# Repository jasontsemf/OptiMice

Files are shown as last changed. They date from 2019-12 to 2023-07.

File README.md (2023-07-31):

# OptiMice

OptiMice

## Intro

> "Bespoke computer mice powered by AI and 3D printing"

[Learn more about the project](https://jasontsemf.github.io/optimice.html) on Jason's portfolio site

## Complementary Web Platform

[Live on Back4App](https://optimice-jasontsemf.b4a.run).

[GitHub Repo](https://github.com/jasontsemf/OptimiceDashboard) of the web platform

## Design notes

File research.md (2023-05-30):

# Links
[PixArt Imaging Inc. - PRODUCTS - PAW3519DL-TKST ](https://www.pixart.com/products-detail/22/PAW3519DL-TKST)

[PixArt Imaging Inc. - PRODUCTS - PAW3212DB-TJDT ](https://www.pixart.com/products-detail/20/PAW3212DB-TJDT)

[PAW3519DL Datasheet, PDF - Alldatasheet](https://www.alldatasheet.com/view.jsp?Searchword=PAW3519DL)

[PAW3205DB-TJ3T Datasheet PDF - Pixart Imaging Inc.](https://pdf1.alldatasheet.com/datasheet-pdf/view/558655/PIXART/PAW3205DB-TJ3T.html)

[PAW3515DB Datasheet (PDF) - Pixart Imaging Inc.](https://pdf1.alldatasheet.com/datasheet-pdf/view/558660/PIXART/PAW3515DB.html)

[Arduino HID Project 2.6.1](https://github.com/NicoHood/HID/blob/master/Readme.md)

[Computer mouse](https://homofaciens.de/technics-base-circuits-computer-mouse_en.htm)

[Optical mouse hacking, part 1](https://conorpeterson.wordpress.com/2010/06/04/optical-mouse-hacking-part-1/)

[Hacked Optical Mouse](https://hackteria.org/wiki/Hacked_Optical_Mouse)

[brush_mouse.ino inoセンサなしで動くよう微調整とUIブラッシュアップ](https://github.com/moritanian/BrushMouse/blob/master/brush_mouse/brush_mouse.ino)

[DeqingSun/UX-Week-2018-Workshop](https://github.com/DeqingSun/UX-Week-2018-Workshop/tree/developPackage)

[sandeepmistry/arduino-BLEPeripheral: An Arduino library for creating custom BLE peripherals with Nordic Semiconductor's nRF8001 or nR51822](https://github.com/sandeepmistry/arduino-BLEPeripheral)

[sandeepmistry/arduino-nRF5: Arduino Core for Nordic Semiconductor nRF5 based boards](https://github.com/sandeepmistry/arduino-nRF5#flashing-a-softdevice)

[arduino-BLEPeripheral/examples at master · sandeepmistry/arduino-BLEPeripheral](https://github.com/sandeepmistry/arduino-BLEPeripheral/tree/master/examples)

[sandeepmistry/arduino-nRF5](https://github.com/sandeepmistry/arduino-nRF5#flashing-a-softdevice)

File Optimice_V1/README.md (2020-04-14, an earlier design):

# OptiMice

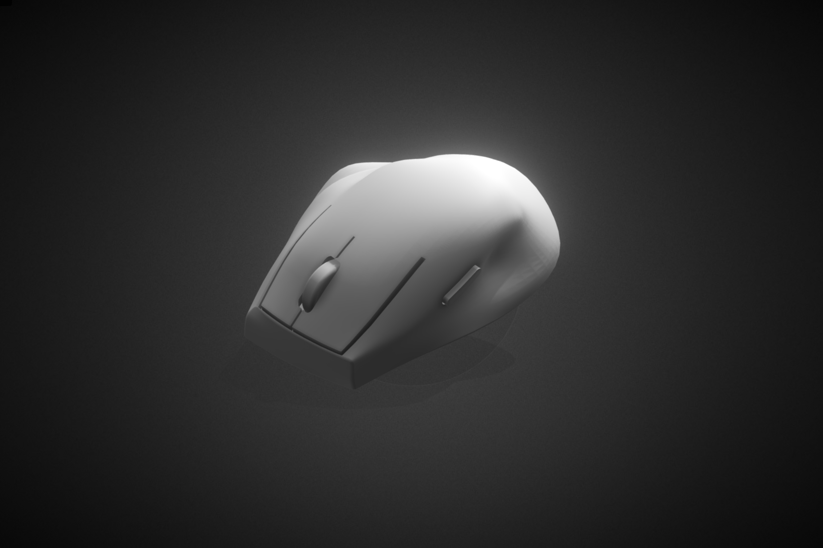
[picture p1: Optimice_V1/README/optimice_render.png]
OptiMice


## Intro

> "OptiMice is a novel, online customer experience which offers tailor-made computer mice to professional computer users who value ergonomics, productivity and customization by harnessing 3D printing and photogrammetry technology."

[Learn more about the project](https://jasontsemf.github.io/optimice.html) on Jason's portfolio site

## Complementary Web Platform

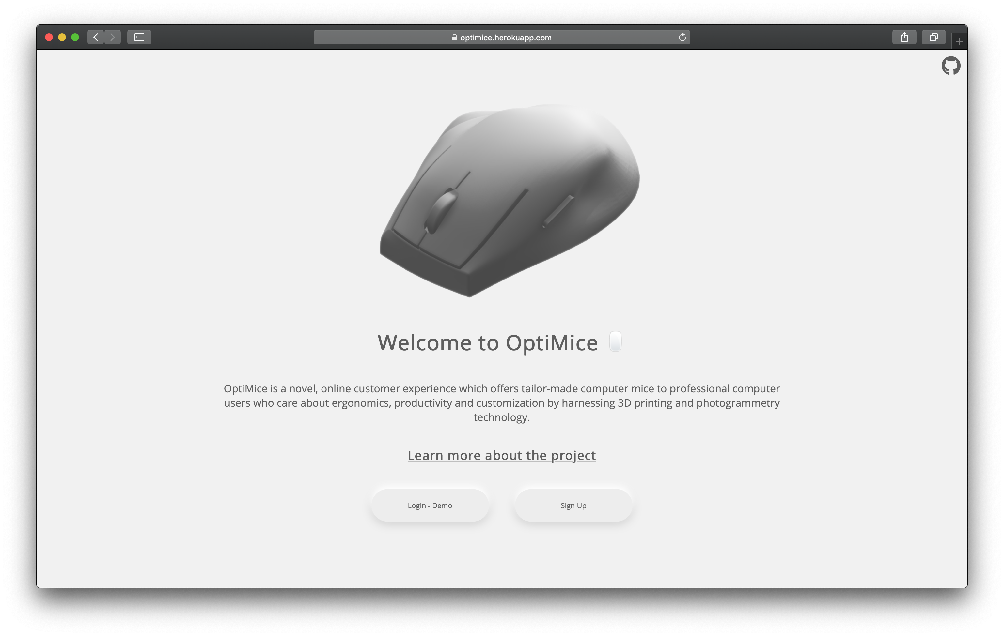
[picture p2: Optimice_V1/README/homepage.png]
Web Platform


[Live on Heroku](https://optimice.herokuapp.com/) working in progress.

[GitHub Repo](https://github.com/jasontsemf/OptimiceDashboard) of the web platform

## Video Demos

OptiMice in 30sec (http://www.youtube.com/watch?v=HUqzL-0pyRI "OptiMice in 30sec")

OptiMice Optical sensor over Bluetooth (http://www.youtube.com/watch?v=QQ9oYC2MPyM "OptiMice Optical sensor over Bluetooth")

## Presentation

[Link to Google Slide](https://docs.google.com/presentation/d/1tQIoXVUgUf5d4TsgJXfUaHyZ3wD5bcfRX4gObf0h1YQ/edit?usp=sharing "OptiMice - Prototyping Electronics Devices Final Present")

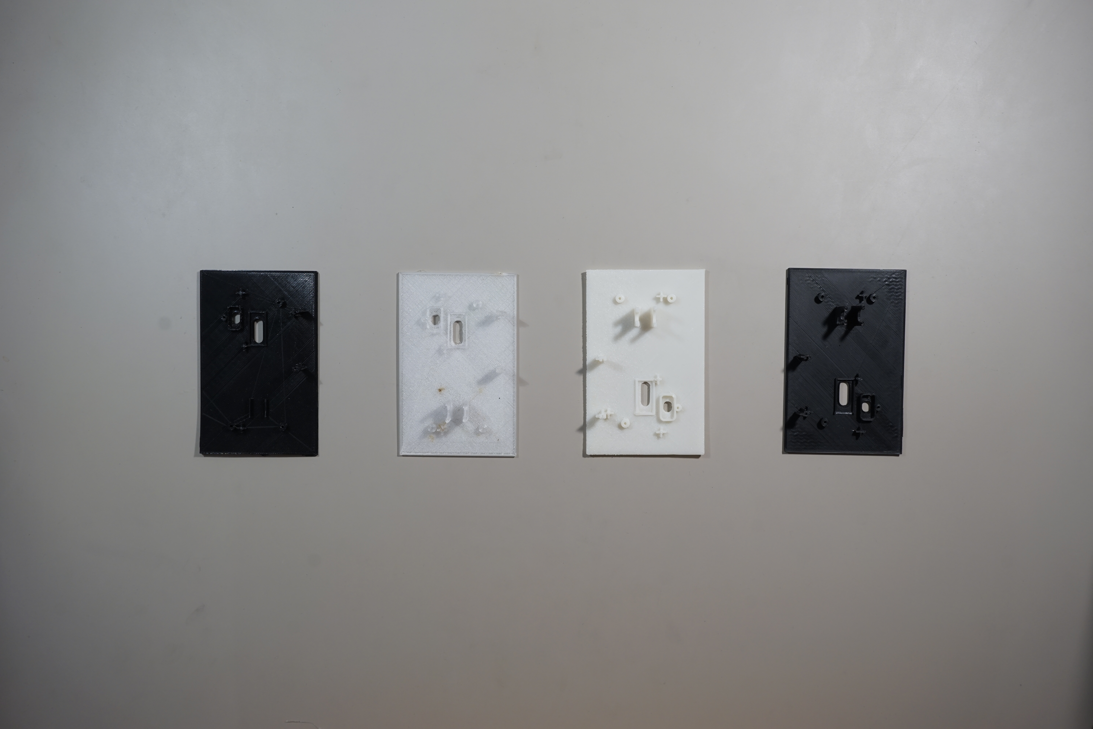
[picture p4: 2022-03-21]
Optimice_V2/img/_DSC0002.JPG

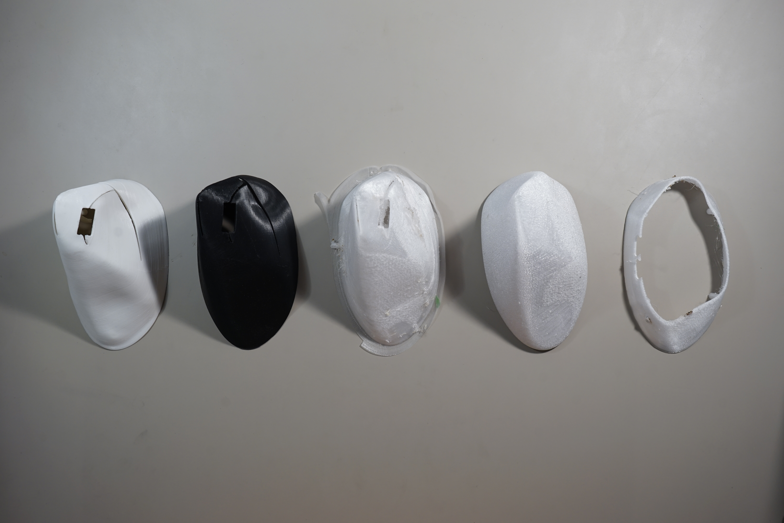
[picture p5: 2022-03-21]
Optimice_V2/img/_DSC0004.JPG

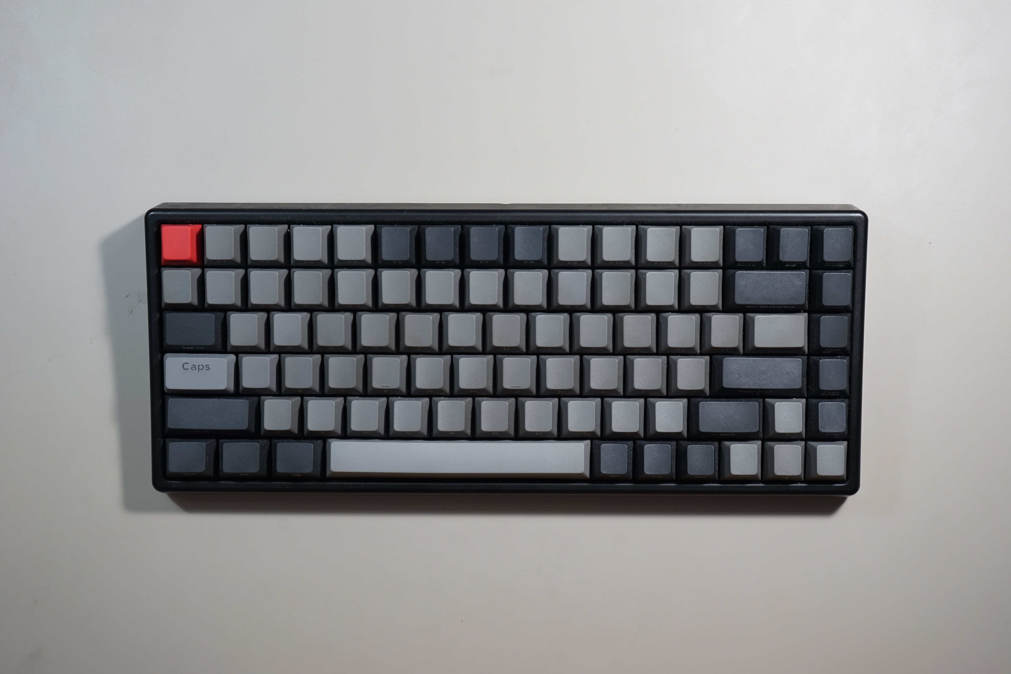
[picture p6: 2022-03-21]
Optimice_V2/img/_DSC0005.JPG

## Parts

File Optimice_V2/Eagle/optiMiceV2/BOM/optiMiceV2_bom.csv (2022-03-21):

Part | Value | Device | Package | Description | AVAILABILITY | BOM | CATEGORY | COMMENT | CURRENT_RATING | DESCRIPTION | MANUFACTURER | MF | MP | MPN | OPERATING_TEMP | PACKAGE | PART_STATUS | POPULARITY | PRICE | PROD_ID | PURCHASE-URL | ROHS_COMPLIANT | SERIES | SPICEPREFIX | SUB-CATEGORY | THERMALLOSS | TYPE | VALUE
BAT | B2B-PH-K-S(LF)(SN) | B2B-PH-K-S(LF)(SN) | JST_B2B-PH-K-S(LF)(SN) | PH Series 2 Position 2 mm Pitch Through Hole Top Entry Shrouded Header Check prices | Good |  |  |  |  | Connector Header Through Hole 2 position 0.079 (2.00mm) |  | JST Sales | B2B-PH-K-S(LF)(SN) |  |  | None |  |  | None |  | https://pricing.snapeda.com/search/part/B2B-PH-K-S(LF)(SN)/?ref=eda
C1 | 1uF | C-USC0805K | C0805K | CAPACITOR, American symbol |  |  |  |  |  |  |  |  |  |  |  |  |  | 19 |  |  |  |  |  | C
C2 | 10uF | C-USC0805K | C0805K | CAPACITOR, American symbol |  |  |  |  |  |  |  |  |  |  |  |  |  | 19 |  |  |  |  |  | C
C3 | 0.1uF | C-EUC0805K | C0805K | CAPACITOR, European symbol |  |  |  |  |  |  |  |  |  |  |  |  |  | 52 |  |  |  |  |  | C
C4 | 100nF | C-EUC0805 | C0805 | CAPACITOR, European symbol |  |  |  |  |  |  |  |  |  |  |  |  |  | 88 |  |  |  |  |  | C
C5 | 100nF | C-EUC0805 | C0805 | CAPACITOR, European symbol |  |  |  |  |  |  |  |  |  |  |  |  |  | 88 |  |  |  |  |  | C
C6 | 10uF | C-EUC0805 | C0805 | CAPACITOR, European symbol |  |  |  |  |  |  |  |  |  |  |  |  |  | 88 |  |  |  |  |  | C
C7 | 4.7uF | C-EUC0805 | C0805 | CAPACITOR, European symbol |  |  |  |  |  |  |  |  |  |  |  |  |  | 88 |  |  |  |  |  | C
C8 | 22uF | C-EUC0805 | C0805 | CAPACITOR, European symbol |  |  |  |  |  |  |  |  |  |  |  |  |  | 88 |  |  |  |  |  | C
HOLE1 | HOLES_MOUNT-PAD-ROUND-0.096-NS | HOLES_MOUNT-PAD-ROUND-0.096-NS | HOLES_096-PAD-NS | MOUNTING PAD, round |  | EXCLUDE
HOLE2 | HOLES_MOUNT-PAD-ROUND-0.096-NS | HOLES_MOUNT-PAD-ROUND-0.096-NS | HOLES_096-PAD-NS | MOUNTING PAD, round |  | EXCLUDE
HOLE3 | HOLES_MOUNT-PAD-ROUND-0.096-NS | HOLES_MOUNT-PAD-ROUND-0.096-NS | HOLES_096-PAD-NS | MOUNTING PAD, round |  | EXCLUDE
HOLE4 | HOLES_MOUNT-PAD-ROUND-0.096-NS | HOLES_MOUNT-PAD-ROUND-0.096-NS | HOLES_096-PAD-NS | MOUNTING PAD, round |  | EXCLUDE
IC1 | TP4056 | TP4056 | SOP-8 |  | Unavailable |  |  |  |  | Complete single cell Li-Ion battery with a constant current / constant voltage linear charger |  | NanJing Top Power ASIC Corp. | TP4056 |  |  | Package |  |  | None
IC2 | DW01A | DW01A | SOT23-6 |  | Unavailable |  |  |  |  | One Cell Lithium-ion/Polymer Battery Protection IC |  | Fortune Semiconductor | DW01A |  |  | SOT-23-6 Fortune Semiconductor |  |  | None
J1 | 10103592-0001LF | 10103592-0001LF | AMPHENOL_10103592-0001LF | Conn Micro USB Type B RCP 5 POS 0.65mm Solder RA SMD 5 Terminal 1 Port T/R Check prices | Good |  |  |  |  | USB - micro B USB 2.0 Receptacle Connector 5 Position Surface Mount, Right Angle | Through Hole |  | Amphenol ICC (FCI) | 10103592-0001LF |  |  | None |  |  | None |  | https://pricing.snapeda.com/search/part/10103592-0001LF/?ref=eda
J3 | 5V | CONN_02 | 1X02 | Multi connection point. Often used as Generic Header-pin footprint for 0.1 inch spaced/style header connections
J4 | PROG | CONN_04 | 1X04 | Multi connection point. Often used as Generic Header-pin footprint for 0.1 inch spaced/style header connections |  |  |  |  |  |  |  |  |  |  |  |  |  |  |  | CONN-09696
J7 | B2B-PH-K-S(LF)(SN) | B2B-PH-K-S(LF)(SN) | JST_B2B-PH-K-S(LF)(SN) | PH Series 2 Position 2 mm Pitch Through Hole Top Entry Shrouded Header Check prices | Good |  |  |  |  | Connector Header Through Hole 2 position 0.079 (2.00mm) |  | JST Sales | B2B-PH-K-S(LF)(SN) |  |  | None |  |  | None |  | https://pricing.snapeda.com/search/part/B2B-PH-K-S(LF)(SN)/?ref=eda
J8 | B2B-PH-K-S(LF)(SN) | B2B-PH-K-S(LF)(SN) | JST_B2B-PH-K-S(LF)(SN) | PH Series 2 Position 2 mm Pitch Through Hole Top Entry Shrouded Header Check prices | Good |  |  |  |  | Connector Header Through Hole 2 position 0.079 (2.00mm) |  | JST Sales | B2B-PH-K-S(LF)(SN) |  |  | None |  |  | None |  | https://pricing.snapeda.com/search/part/B2B-PH-K-S(LF)(SN)/?ref=eda
L1 | 4.7uH | L_CHIP-0805(2012-METRIC) | INDC2009X120 | Inductor Fixed - Generic |  |  | Inductor |  |  |  |  |  |  |  |  |  |  |  |  |  |  |  |  |  | Fixed
LED1 | RED | LED5MM | LED5MM | LED |  |  |  |  |  |  |  |  |  |  |  |  |  | 93
LED_G | GREEN | LEDCHIP-LED0805 | CHIP-LED0805 | LED |  |  |  |  |  |  |  |  |  |  |  |  |  | 68
LED_R | RED | LEDCHIP-LED0805 | CHIP-LED0805 | LED |  |  |  |  |  |  |  |  |  |  |  |  |  | 68
Q1 | FS8205A | FS8205A | SOP65P640X120-8N | N/A | Unavailable |  |  |  |  |  |  | Fortune Semiconductor | FS8205A |  |  | Package |  |  | None
R1 | 10K | R-US_R0805 | R0805 | RESISTOR, American symbol |  |  |  |  |  |  |  |  |  |  |  |  |  | 85 |  |  |  |  |  | R
R2 | 10K | R-US_R0805 | R0805 | RESISTOR, American symbol |  |  |  |  |  |  |  |  |  |  |  |  |  | 85 |  |  |  |  |  | R
R3 | 10K | R-US_R0805 | R0805 | RESISTOR, American symbol |  |  |  |  |  |  |  |  |  |  |  |  |  | 85 |  |  |  |  |  | R
R4 | 10K | R-US_R0805 | R0805 | RESISTOR, American symbol |  |  |  |  |  |  |  |  |  |  |  |  |  | 85 |  |  |  |  |  | R
R5 | 10K | R-US_R0805 | R0805 | RESISTOR, American symbol |  |  |  |  |  |  |  |  |  |  |  |  |  | 85 |  |  |  |  |  | R
R6 | 22 | R-US_R0805 | R0805 | RESISTOR, American symbol |  |  |  |  |  |  |  |  |  |  |  |  |  | 85 |  |  |  |  |  | R
R7 | 1K | R-US_R0805 | R0805 | RESISTOR, American symbol |  |  |  |  |  |  |  |  |  |  |  |  |  | 85 |  |  |  |  |  | R
R8 | 1K | R-US_R0805 | R0805 | RESISTOR, American symbol |  |  |  |  |  |  |  |  |  |  |  |  |  | 85 |  |  |  |  |  | R
R9 | 1.2K | R-US_R0805 | R0805 | RESISTOR, American symbol |  |  |  |  |  |  |  |  |  |  |  |  |  | 85 |  |  |  |  |  | R
R10 | 1K | R-US_R0805 | R0805 | RESISTOR, American symbol |  |  |  |  |  |  |  |  |  |  |  |  |  | 85 |  |  |  |  |  | R
R11 | 100 | R-US_R0805 | R0805 | RESISTOR, American symbol |  |  |  |  |  |  |  |  |  |  |  |  |  | 85 |  |  |  |  |  | R
R12 | 10K | R-US_R0805 | R0805 | RESISTOR, American symbol |  |  |  |  |  |  |  |  |  |  |  |  |  | 85 |  |  |  |  |  | R
R13 | 10K | R-US_R0805 | R0805 | RESISTOR, American symbol |  |  |  |  |  |  |  |  |  |  |  |  |  | 85 |  |  |  |  |  | R
S1 | D2F-FL | D2F-FL | SW_D2F-FL | SWITCH SNAP ACTION SPDT 1A 125V Check prices | Good |  |  |  |  | SWITCH SNAP ACTION SPDT 1A 125V |  | Omron Electronics | D2F-FL |  |  | MQFP-44 Omron |  |  | None |  | https://pricing.snapeda.com/search/part/D2F-FL/?ref=eda
S2 | D2F-FL | D2F-FL | SW_D2F-FL | SWITCH SNAP ACTION SPDT 1A 125V Check prices | Good |  |  |  |  | SWITCH SNAP ACTION SPDT 1A 125V |  | Omron Electronics | D2F-FL |  |  | MQFP-44 Omron |  |  | None |  | https://pricing.snapeda.com/search/part/D2F-FL/?ref=eda
S3 | D2F-FL | D2F-FL | SW_D2F-FL | SWITCH SNAP ACTION SPDT 1A 125V Check prices | Good |  |  |  |  | SWITCH SNAP ACTION SPDT 1A 125V |  | Omron Electronics | D2F-FL |  |  | MQFP-44 Omron |  |  | None |  | https://pricing.snapeda.com/search/part/D2F-FL/?ref=eda
SW1 | MLL1200S | MLL1200S | SW_MLL1200S | Switch Slide SPDT Side Slide 0.3A 4VDC Gull Wing SMD Box Check prices | Good |  |  | 1437575-1 |  | Slide Switch SPDT Surface Mount, Right Angle |  | TE Connectivity | MLL1200S |  |  | None |  |  | None |  | https://pricing.snapeda.com/search/part/MLL1200S/?ref=eda
U$1 | NRF51822-02 | NRF51822-02 | WT51822-S2
U$2 | PAW3205TJ3T | PAW3205TJ3T | PAW3205 | Check prices | Bad |  |  |  |  | Optical Sensor 8-DIP Module |  | Broadcom Limited | ADNS-2080 |  |  | DIP-8 Broadcom Limited |  |  | None
U1 | TPS62203DBVR | TPS62203DBVR | SOT95P280X145-5N | Check prices | Good |  |  |  |  | 3.3-V Output, 300-mA, 95% Efficient Step-Down Converter in SOT-23 5-SOT-23 -40 to 85 |  | Texas Instruments | TPS62203DBVR |  |  | SOT-23-5 Texas Instruments |  |  | None |  | https://pricing.snapeda.com/search/part/TPS62203DBVR/?ref=eda
VR1 | EC10E1220501 | EC10E1220501 | TRIM_EC10E1220501 | Encoders 10mm 12 Res 24 Dtent 9mm mount height Check prices | Good |  |  |  |  | Encoders 10mm 12 Res 24 Dtent 9mm mount height |  | ALPS | EC10E1220501 |  |  | None |  |  | None |  | https://pricing.snapeda.com/search/part/EC10E1220501/?ref=eda

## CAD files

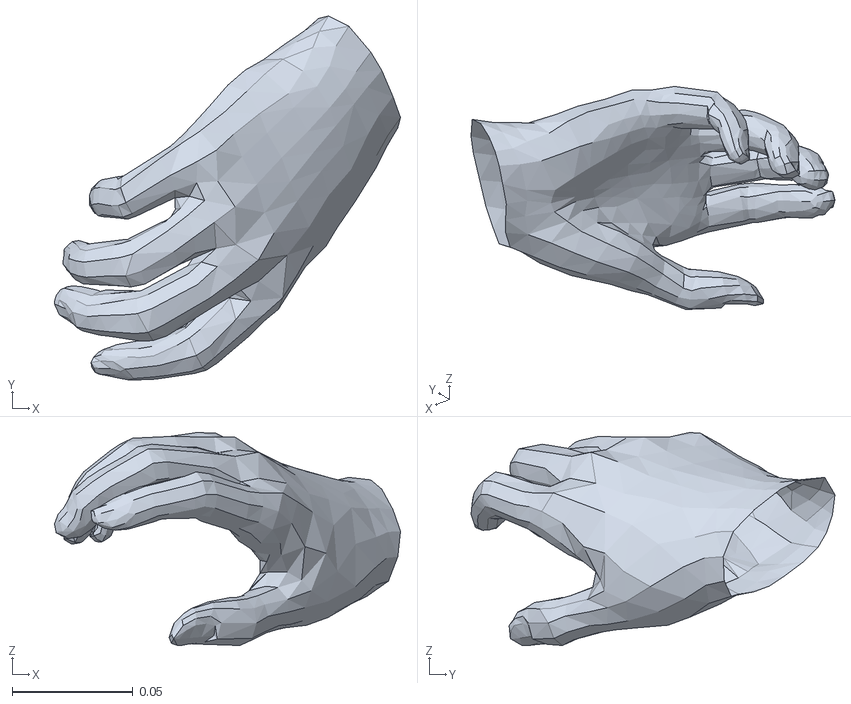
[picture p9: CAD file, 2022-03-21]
Optimice_V2/software/I2L-MeshNet_RELEASE/demo/close_to_perfect/output_mesh_lixel.obj
0.143 x 0.151 x 0.0882

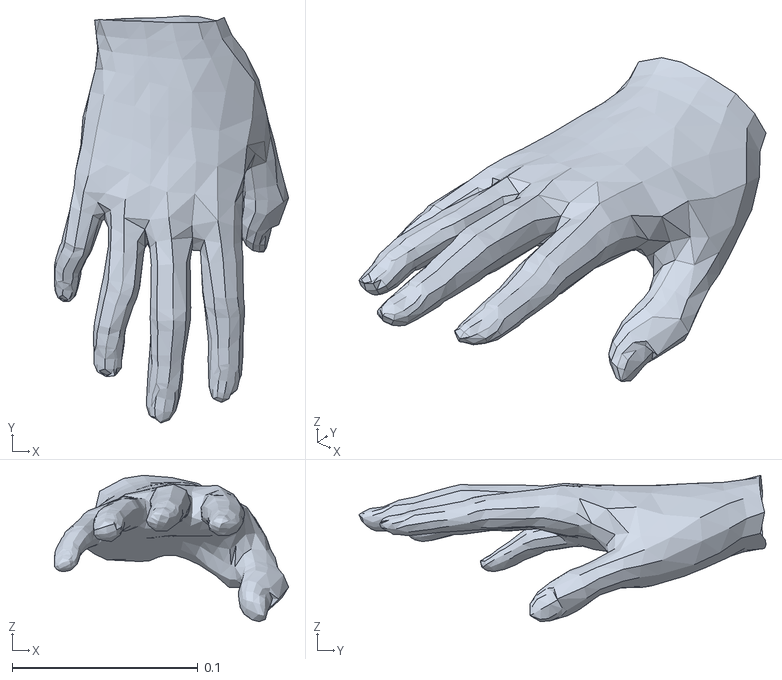
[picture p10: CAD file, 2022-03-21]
Optimice_V2/software/I2L-MeshNet_RELEASE/demo/flat/output_mesh_lixel.obj
0.126 x 0.219 x 0.0788

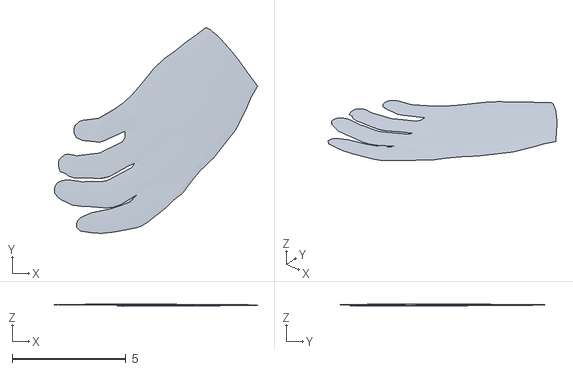
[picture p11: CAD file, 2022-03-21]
Optimice_V2/software/I2L-MeshNet_RELEASE/demo/output_mesh_lixel.obj
8.93 x 9.05 x 0.0882

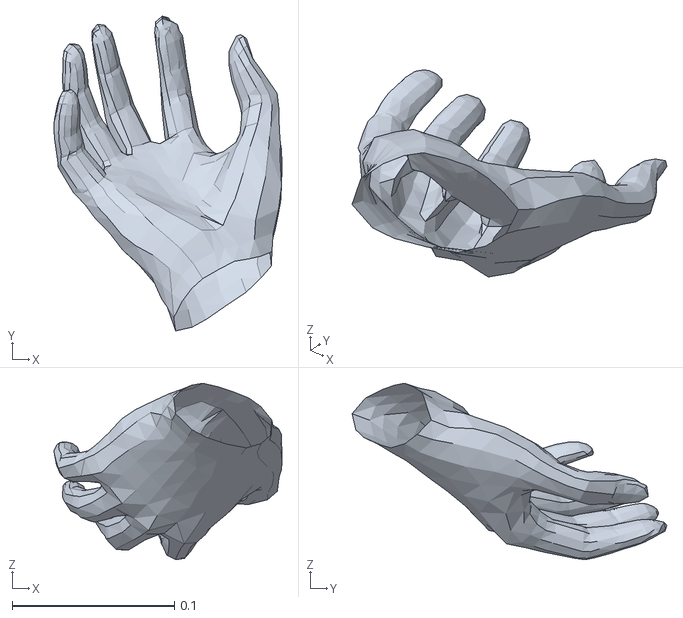
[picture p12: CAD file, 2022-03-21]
Optimice_V2/software/I2L-MeshNet_RELEASE/demo/quite_good/output_mesh_lixel.obj
0.141 x 0.194 x 0.109

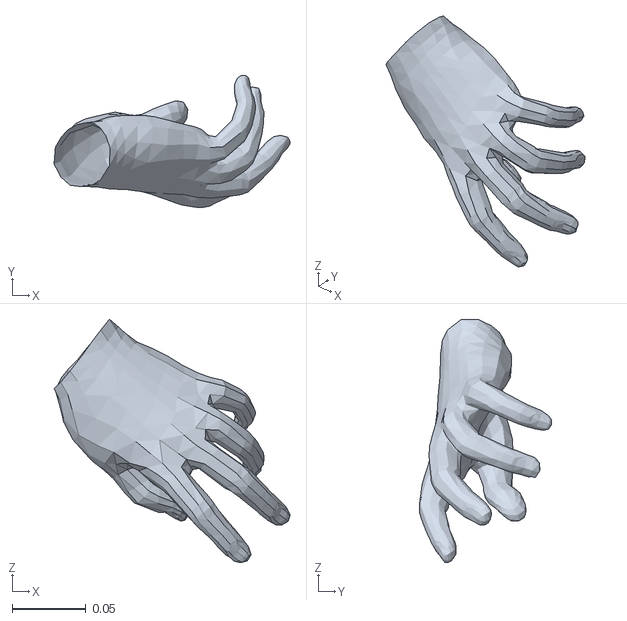
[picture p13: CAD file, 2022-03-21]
Optimice_V2/software/minimal-hand/capture/output_mesh_lixelMar112021181230.obj
0.16 x 0.09 x 0.165

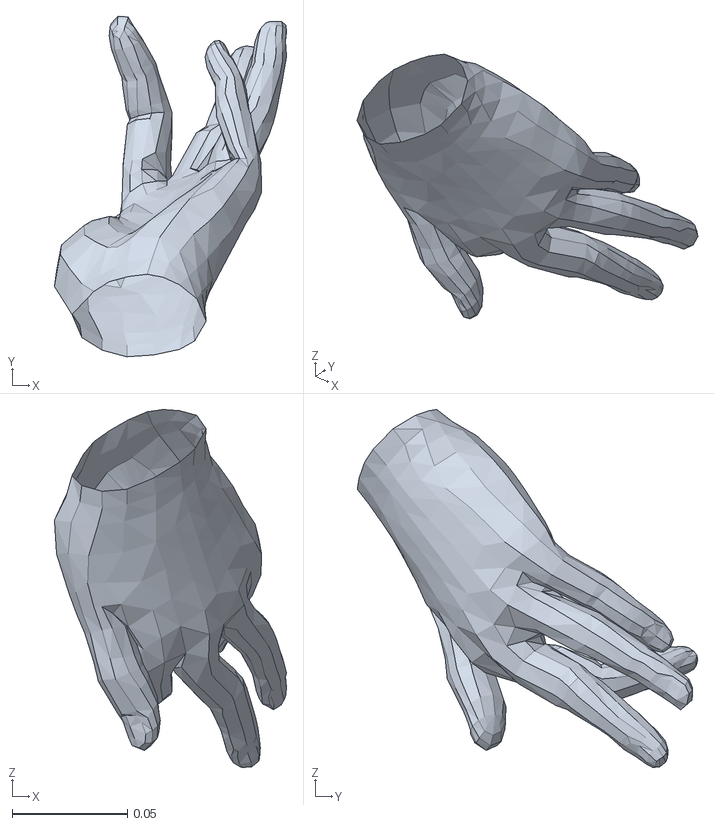
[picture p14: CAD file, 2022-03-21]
Optimice_V2/software/minimal-hand/output_mesh_lixel.obj
0.101 x 0.148 x 0.155

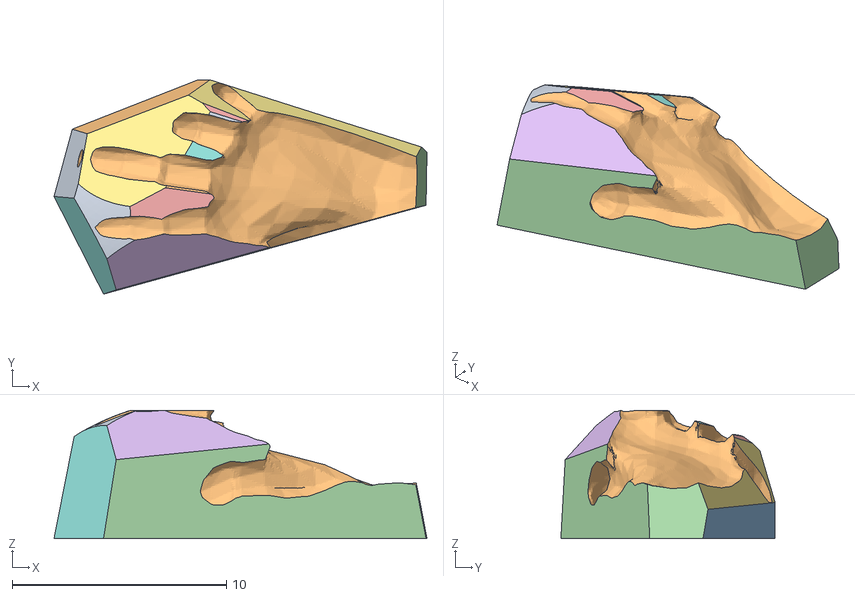
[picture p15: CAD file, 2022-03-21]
Optimice_V2/software/my_hand/jason_hand_1_trim.obj
17.4 x 10.0 x 5.98
mmGroup0
mmGroup15
mmGroup26
mmGroup28
mmGroup33
mmGroup34
mmGroup35
mmGroup36
mmGroup37
mmGroup38
mmGroup39
mmGroup40
mmGroup44
mmGroup45
mmGroup46
mmGroup47
mmGroup48
mmGroup49

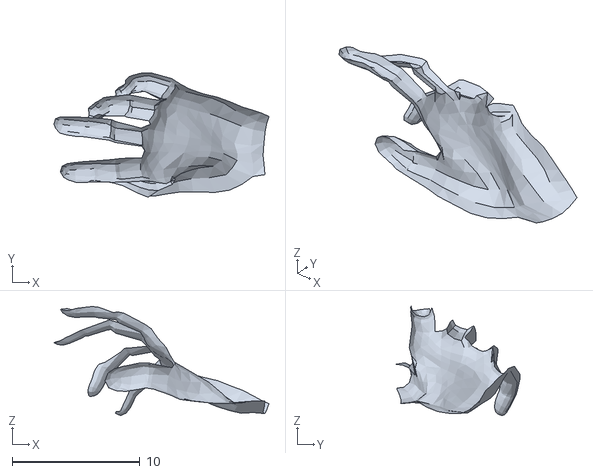
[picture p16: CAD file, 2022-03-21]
Optimice_V2/software/my_hand/second_try/jason_hand_half.obj
16.8 x 9.74 x 8.53

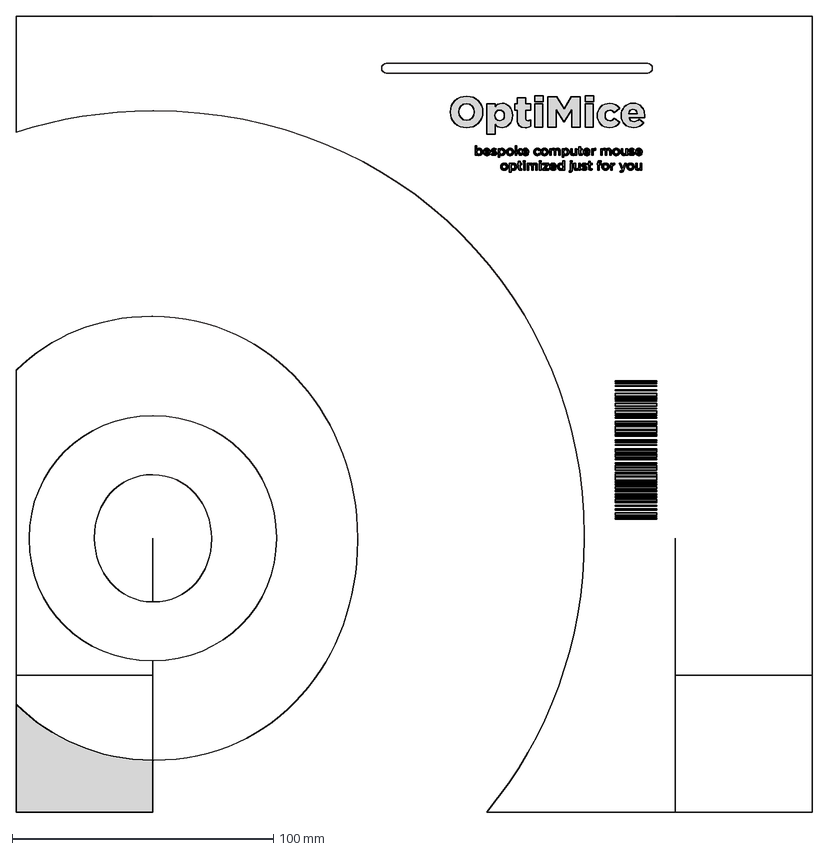
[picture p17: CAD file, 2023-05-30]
V2/packaging/packaging.dxf
304.8 x 304.8 mm

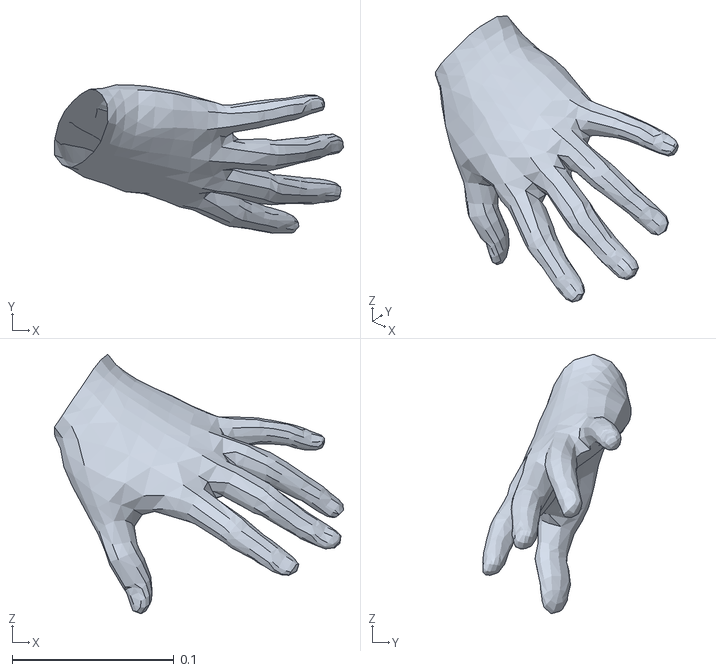
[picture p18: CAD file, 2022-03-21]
Optimice_V2/software/minimal-hand/output_mesh_lixel_1.obj
0.179 x 0.0918 x 0.16

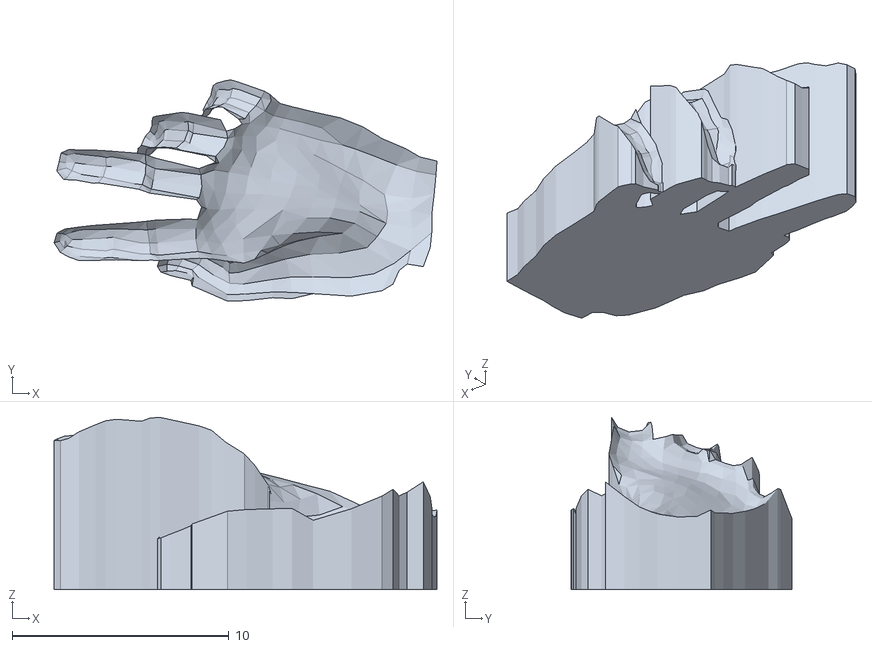
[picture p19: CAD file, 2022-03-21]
Optimice_V2/software/my_hand/mouselike.stl
17.7 x 10.2 x 7.95

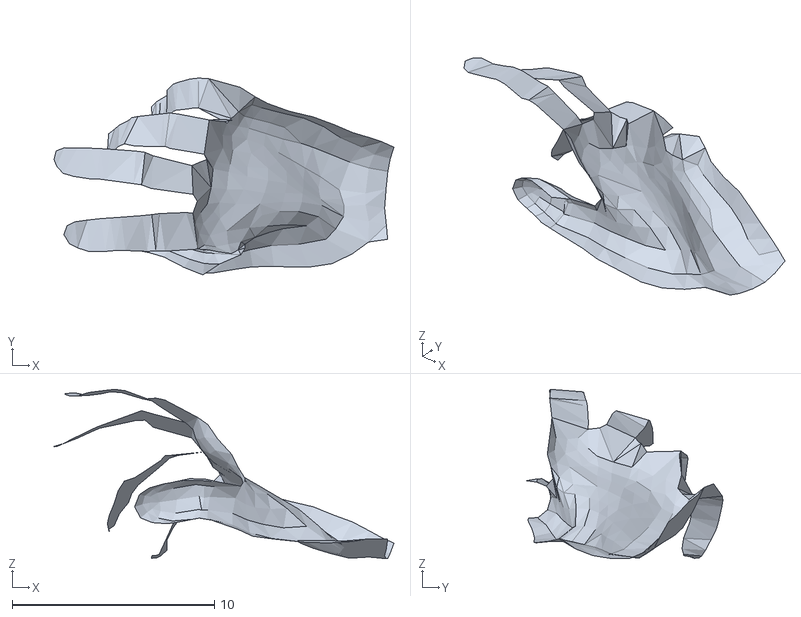
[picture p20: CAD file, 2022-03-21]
Optimice_V2/software/my_hand/second_try/jason_hand_half_flat.obj
16.8 x 9.74 x 8.37

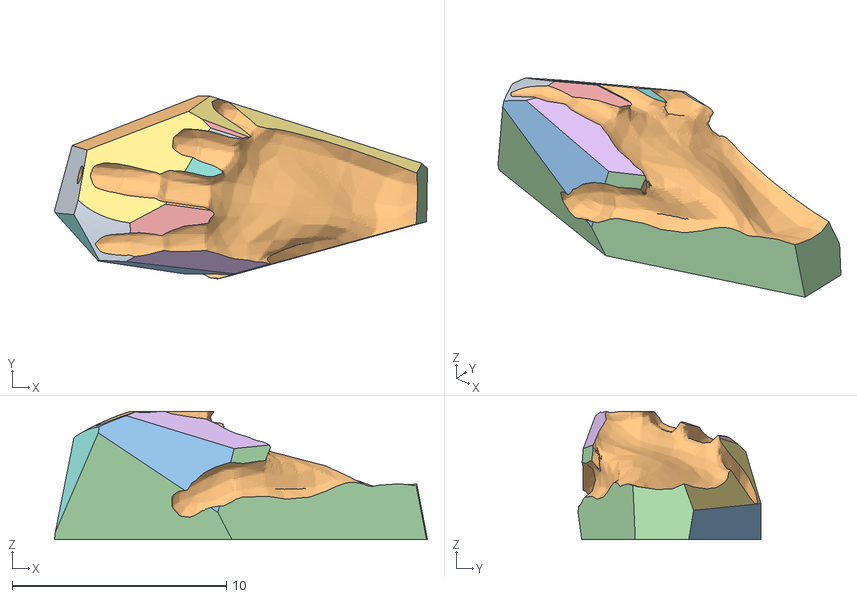
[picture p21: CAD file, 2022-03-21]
Optimice_V2/software/my_hand/jason_hand_1_trim_2.obj
17.4 x 8.53 x 5.98
mmGroup0
mmGroup15
mmGroup26
mmGroup28
mmGroup33
mmGroup34
mmGroup35
mmGroup36
mmGroup37
mmGroup38
mmGroup39
mmGroup40
mmGroup44
mmGroup45
mmGroup46
mmGroup47
mmGroup48
mmGroup49
mmGroup50
mmGroup51

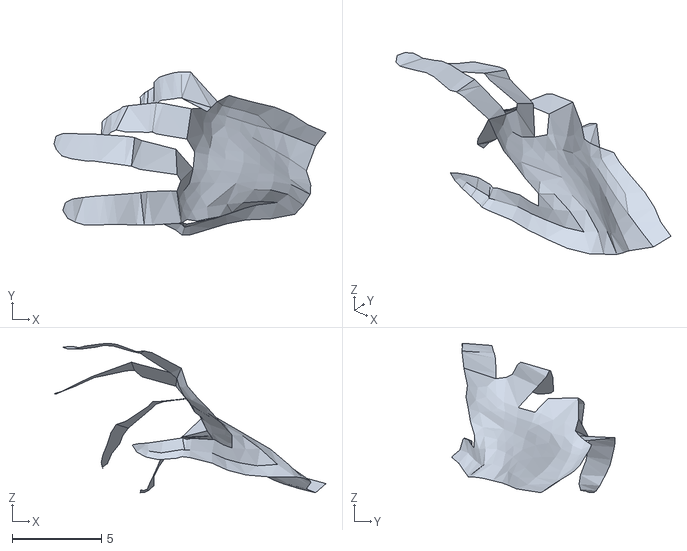
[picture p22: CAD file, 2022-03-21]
Optimice_V2/software/my_hand/second_try/hand_reorient_cuthalf_flat_v2.obj
15.2 x 9.14 x 8.36

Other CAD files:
Optimice_V2/software/my_hand/jason_hand_1_closed.obj
Optimice_V2/software/my_hand/second_try/jason_hand_1.obj
Optimice_V2/software/my_hand/jason_hand_1.obj
Optimice_V2/software/my_hand/second_try/jason_hand_half_minimal.obj
Optimice_V2/software/I2L-MeshNet_RELEASE/demo/old/SMPL/output_mesh_lixel.obj
Optimice_V2/software/I2L-MeshNet_RELEASE/demo/old/SMPL/output_mesh_param.obj
Optimice_V2/software/I2L-MeshNet_RELEASE/demo/old/hand1/output_mesh_lixel.obj
Optimice_V2/software/I2L-MeshNet_RELEASE/demo/old/hand2/output_mesh_lixel.obj
Optimice_V2/software/I2L-MeshNet_RELEASE/demo/old/hand3/output_mesh_lixel.obj
Optimice_V2/software/I2L-MeshNet_RELEASE/demo/old/hand4/output_mesh_lixel.obj
Optimice_V2/software/I2L-MeshNet_RELEASE/demo/old/hand5/output_mesh_lixel.obj
Optimice_V2/software/my_hand/mouselike.obj
Optimice_V2/software/my_hand/second_try/hand_reorient.obj

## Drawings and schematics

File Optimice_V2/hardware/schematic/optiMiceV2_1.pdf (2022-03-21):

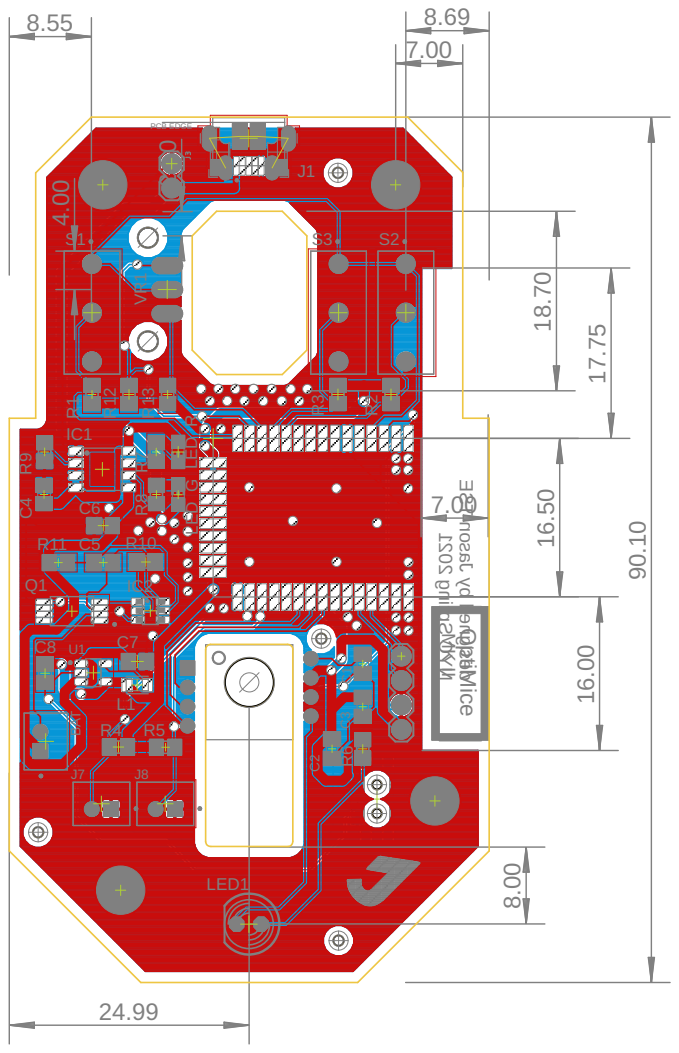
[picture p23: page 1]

designed by Jason TSE NYC Spring 2021 OptiMice MK II 18.70

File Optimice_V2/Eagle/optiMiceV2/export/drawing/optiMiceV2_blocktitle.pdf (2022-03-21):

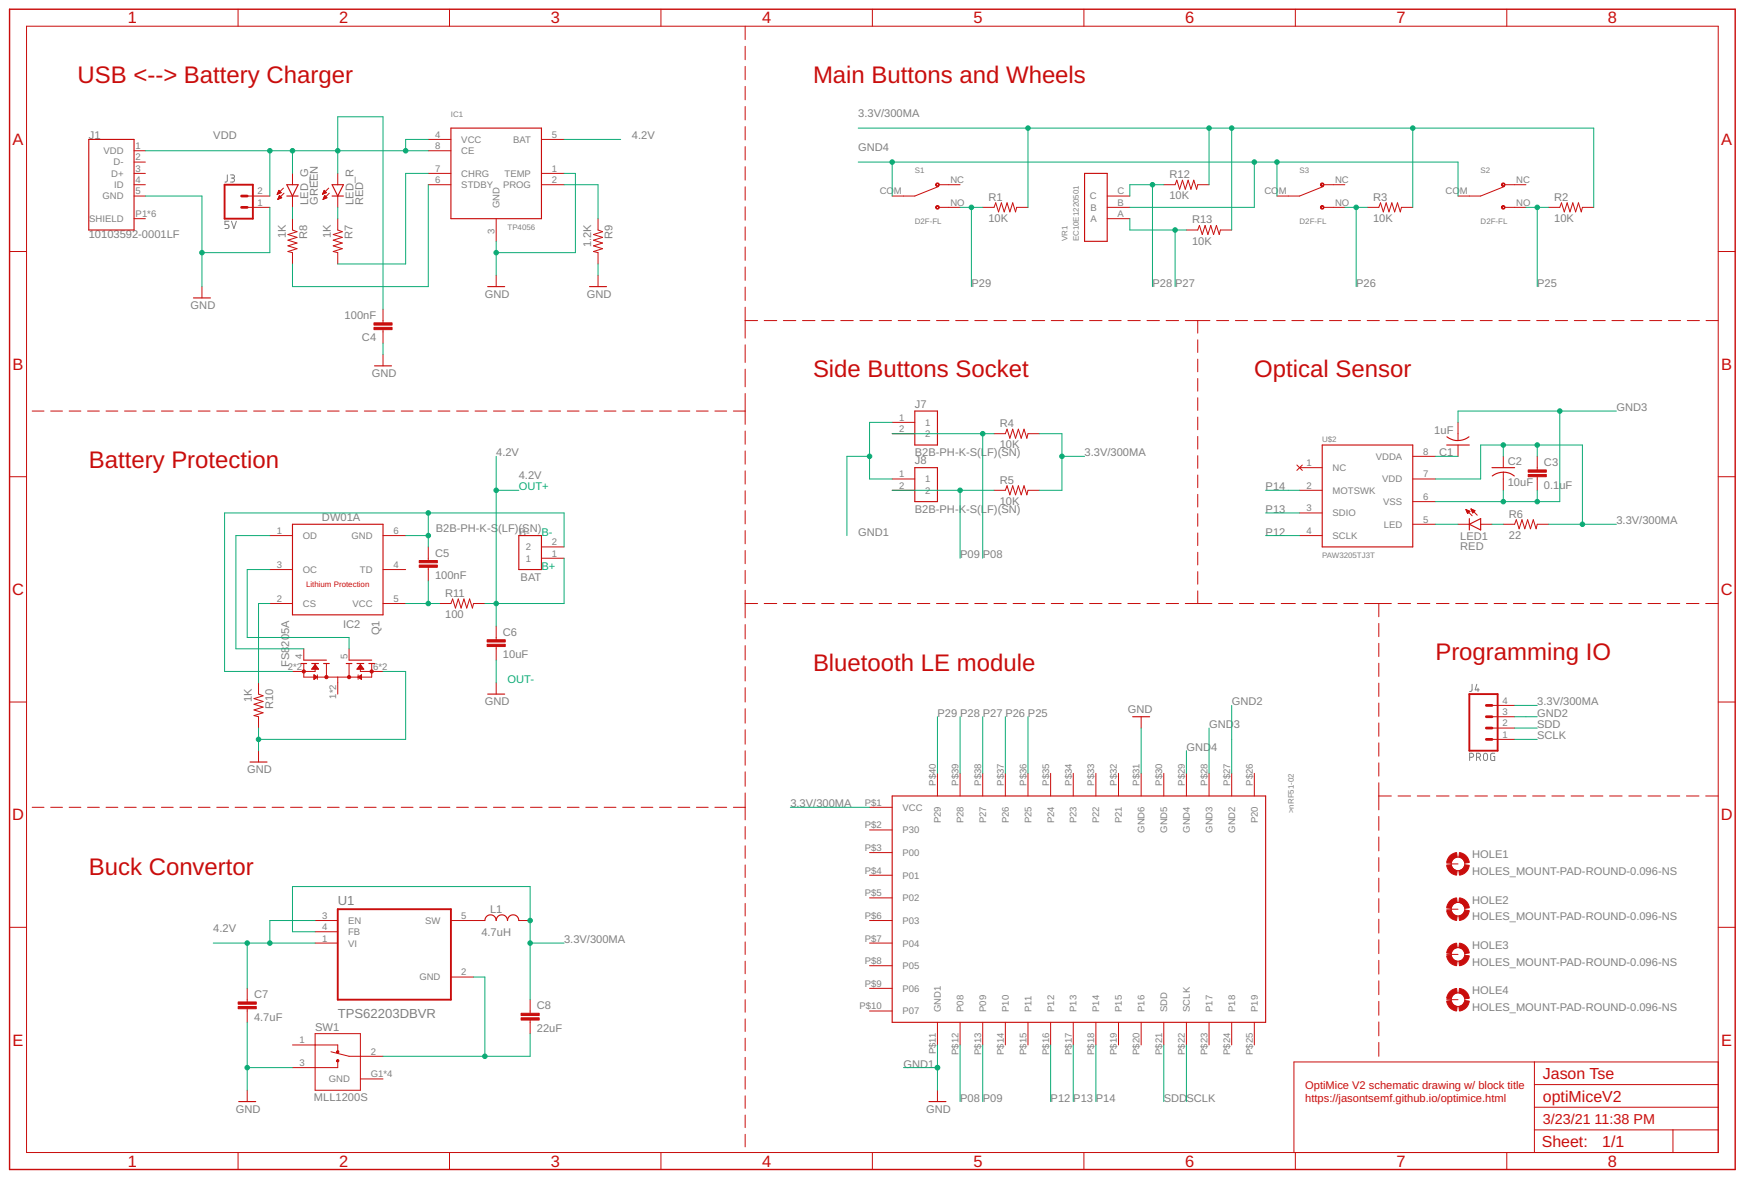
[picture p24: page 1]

Main Buttons and Wheels

Programming IO Bluetooth LE module

OptiMice V2 schematic drawing w/ block title
https://jasontsemf.github.io/optimice.html

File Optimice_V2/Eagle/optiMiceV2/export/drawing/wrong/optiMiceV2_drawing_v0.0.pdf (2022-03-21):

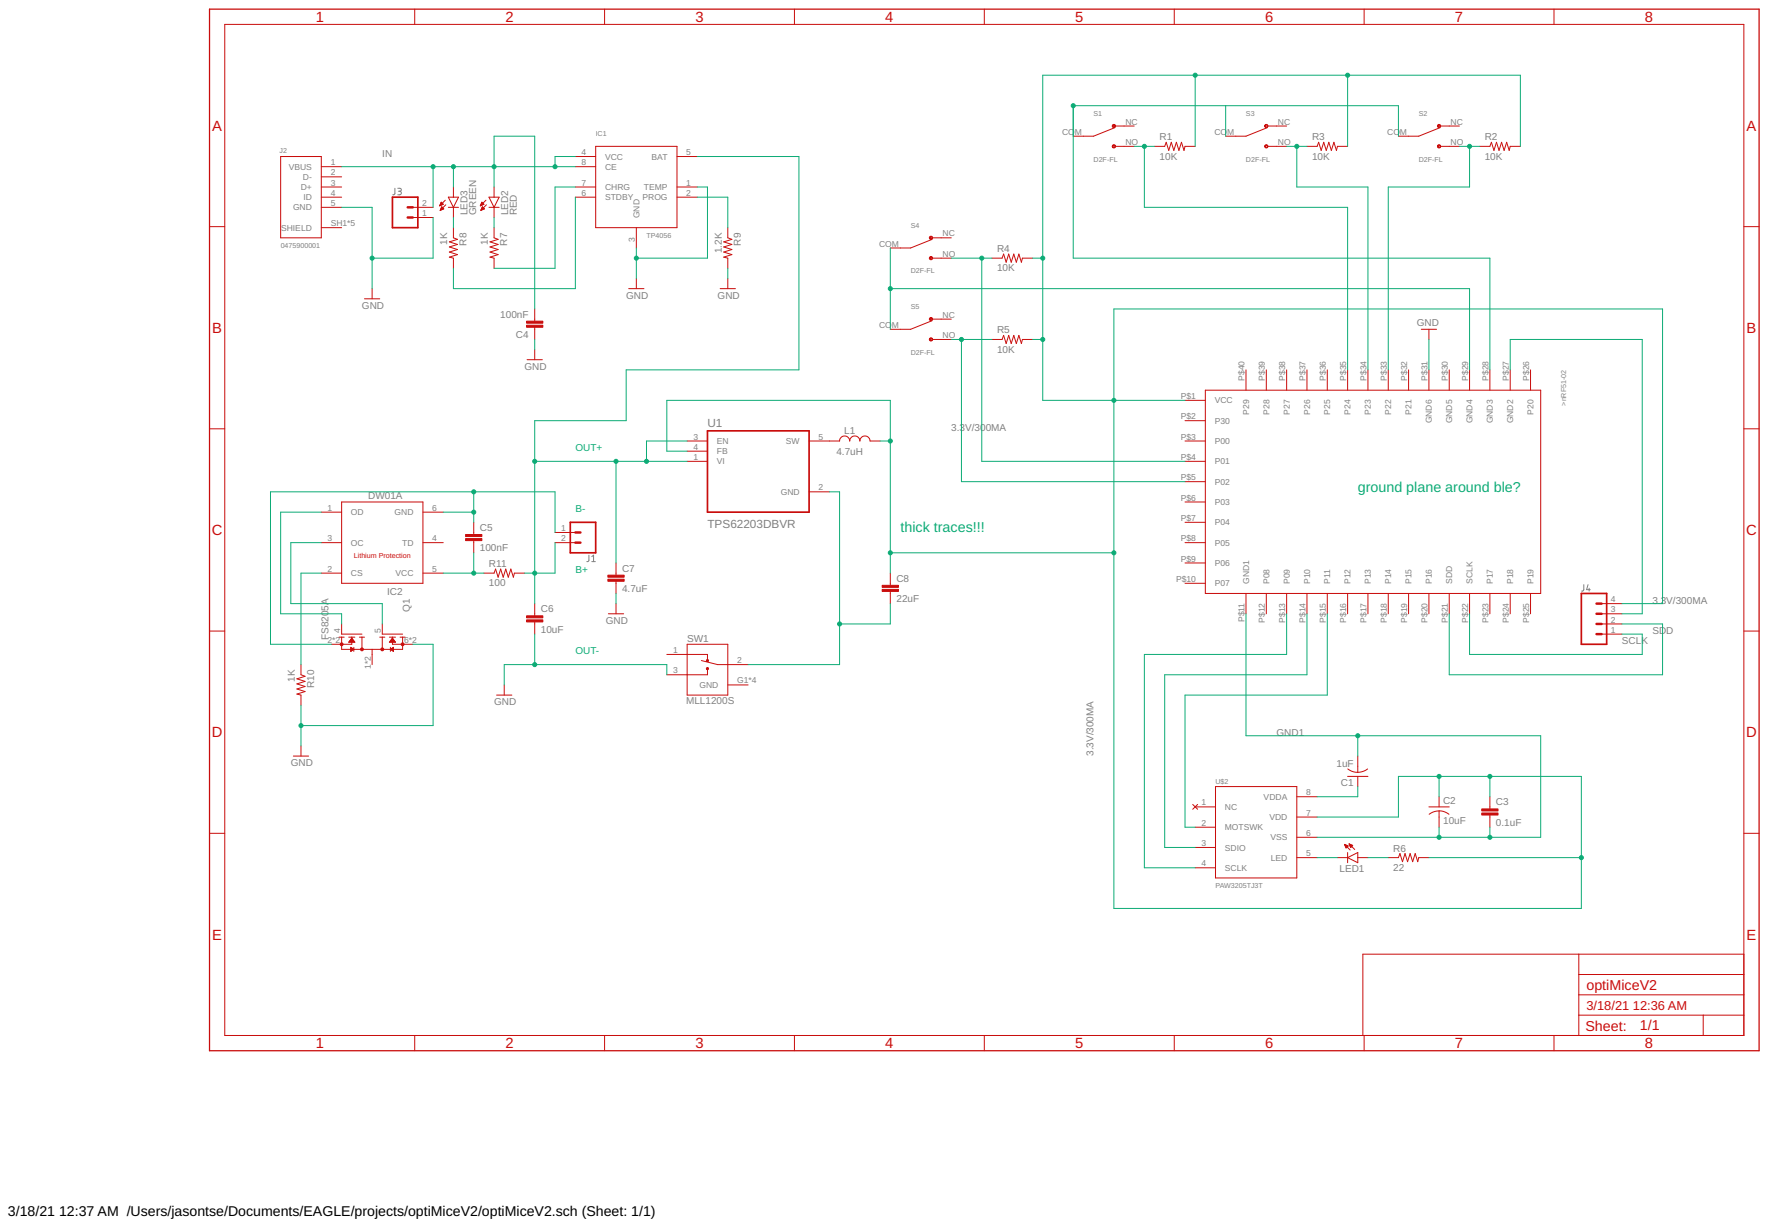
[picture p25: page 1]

ground plane around ble?

3/18/21 12:37 AM /Users/jasontse/Documents/EAGLE/projects/optiMiceV2/optiMiceV2.sch (Sheet: 1/1)

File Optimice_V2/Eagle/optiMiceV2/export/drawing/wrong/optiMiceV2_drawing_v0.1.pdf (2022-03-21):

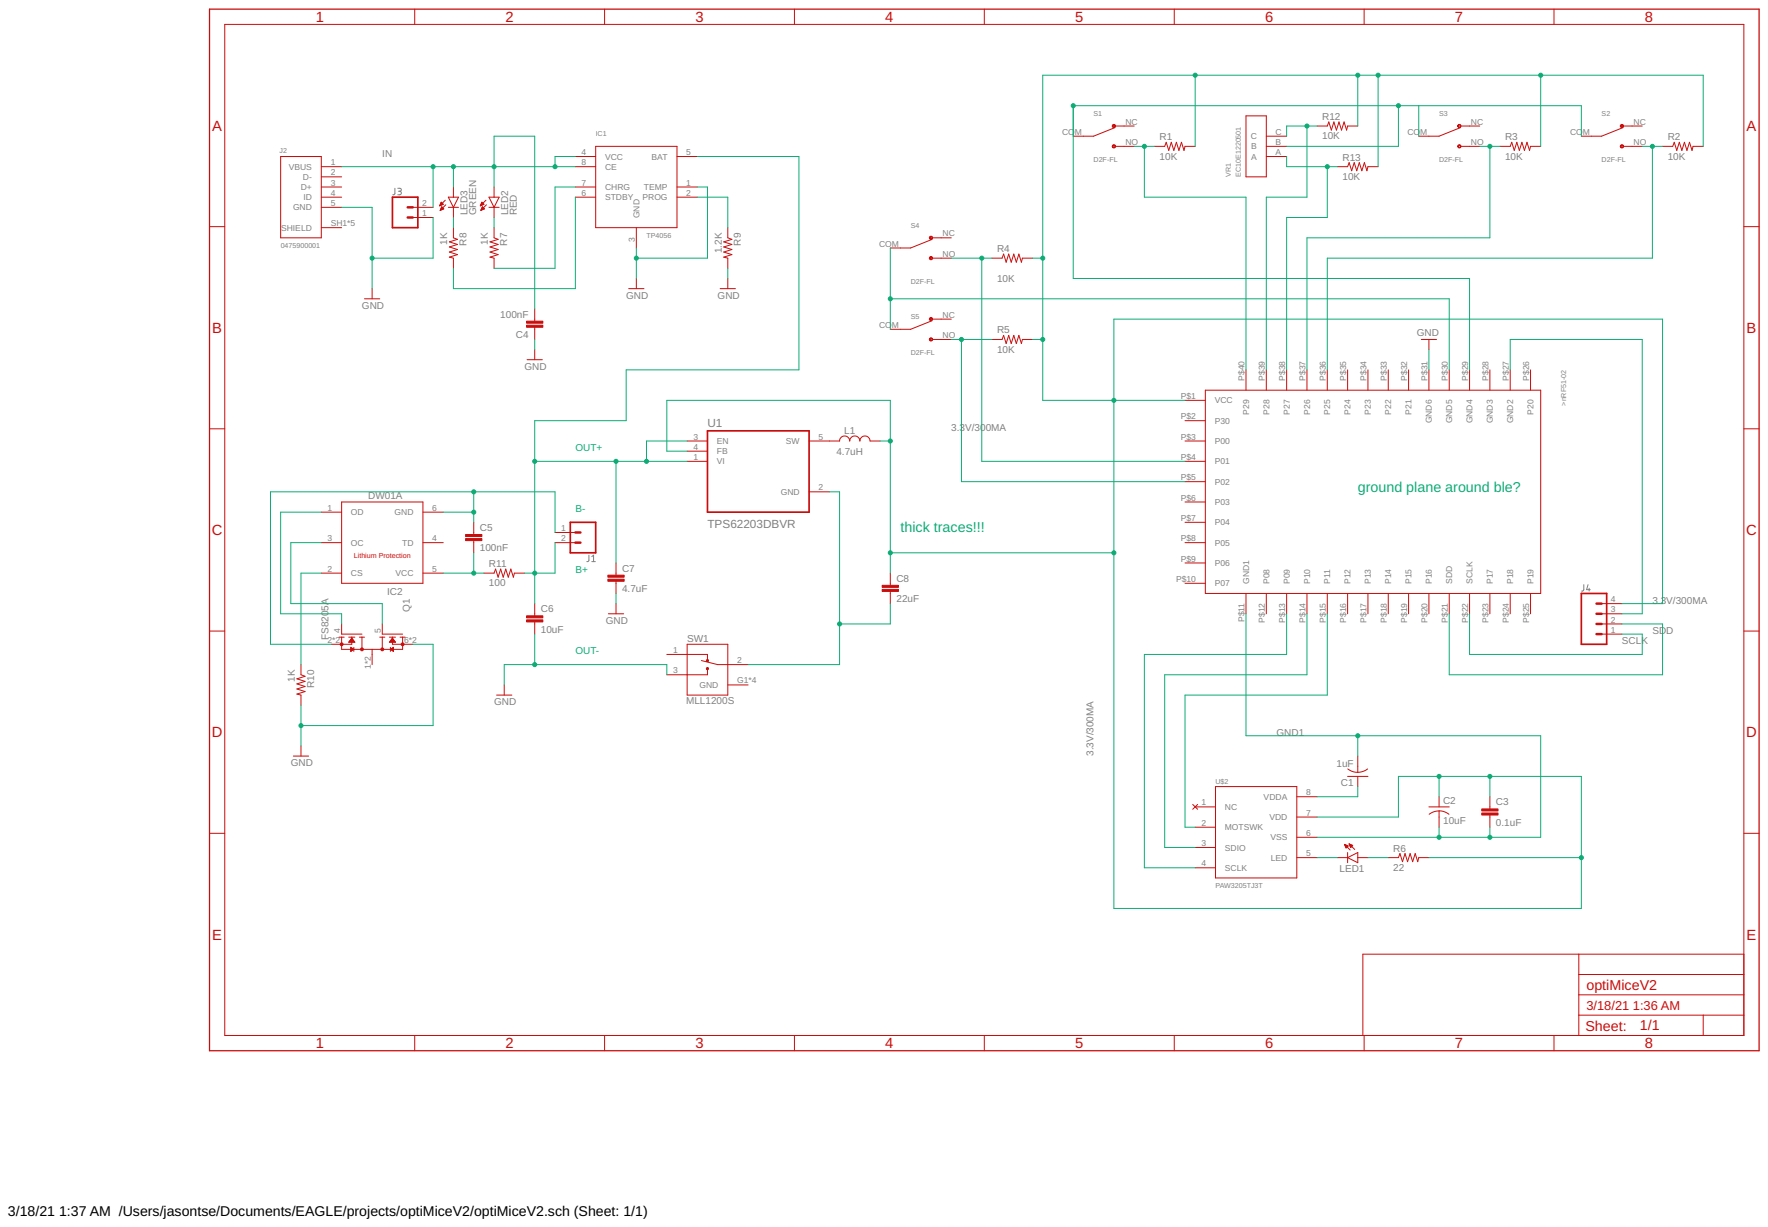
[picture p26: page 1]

ground plane around ble?

3/18/21 1:37 AM /Users/jasontse/Documents/EAGLE/projects/optiMiceV2/optiMiceV2.sch (Sheet: 1/1)

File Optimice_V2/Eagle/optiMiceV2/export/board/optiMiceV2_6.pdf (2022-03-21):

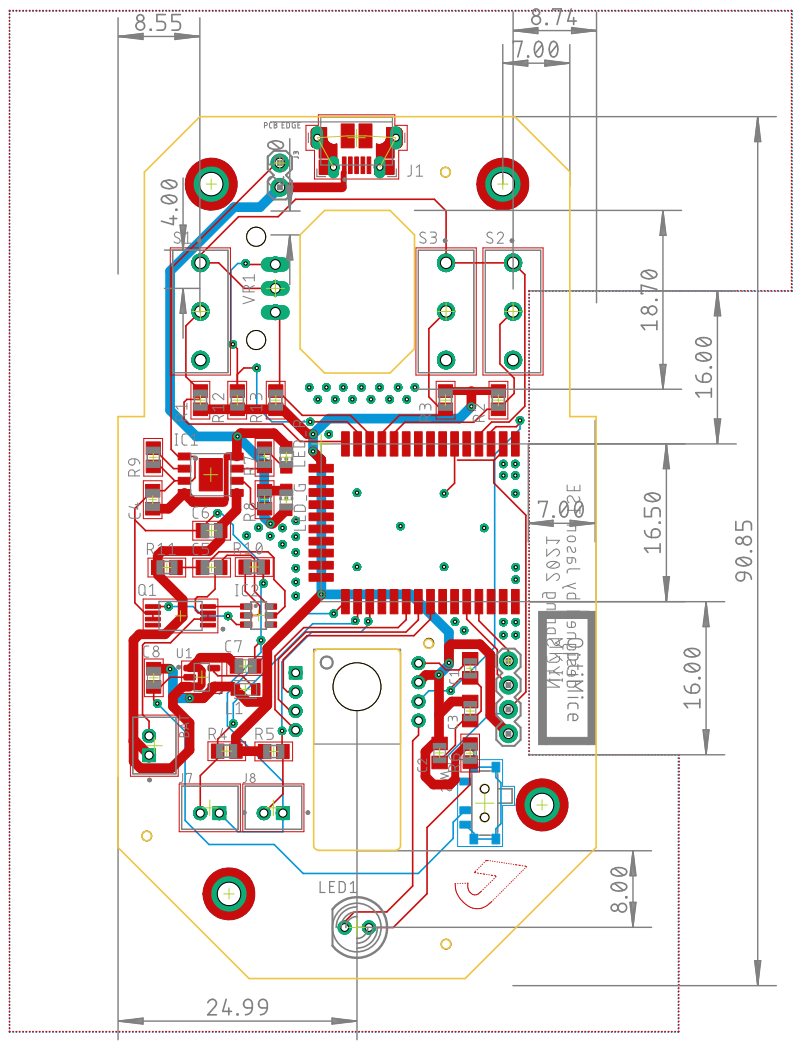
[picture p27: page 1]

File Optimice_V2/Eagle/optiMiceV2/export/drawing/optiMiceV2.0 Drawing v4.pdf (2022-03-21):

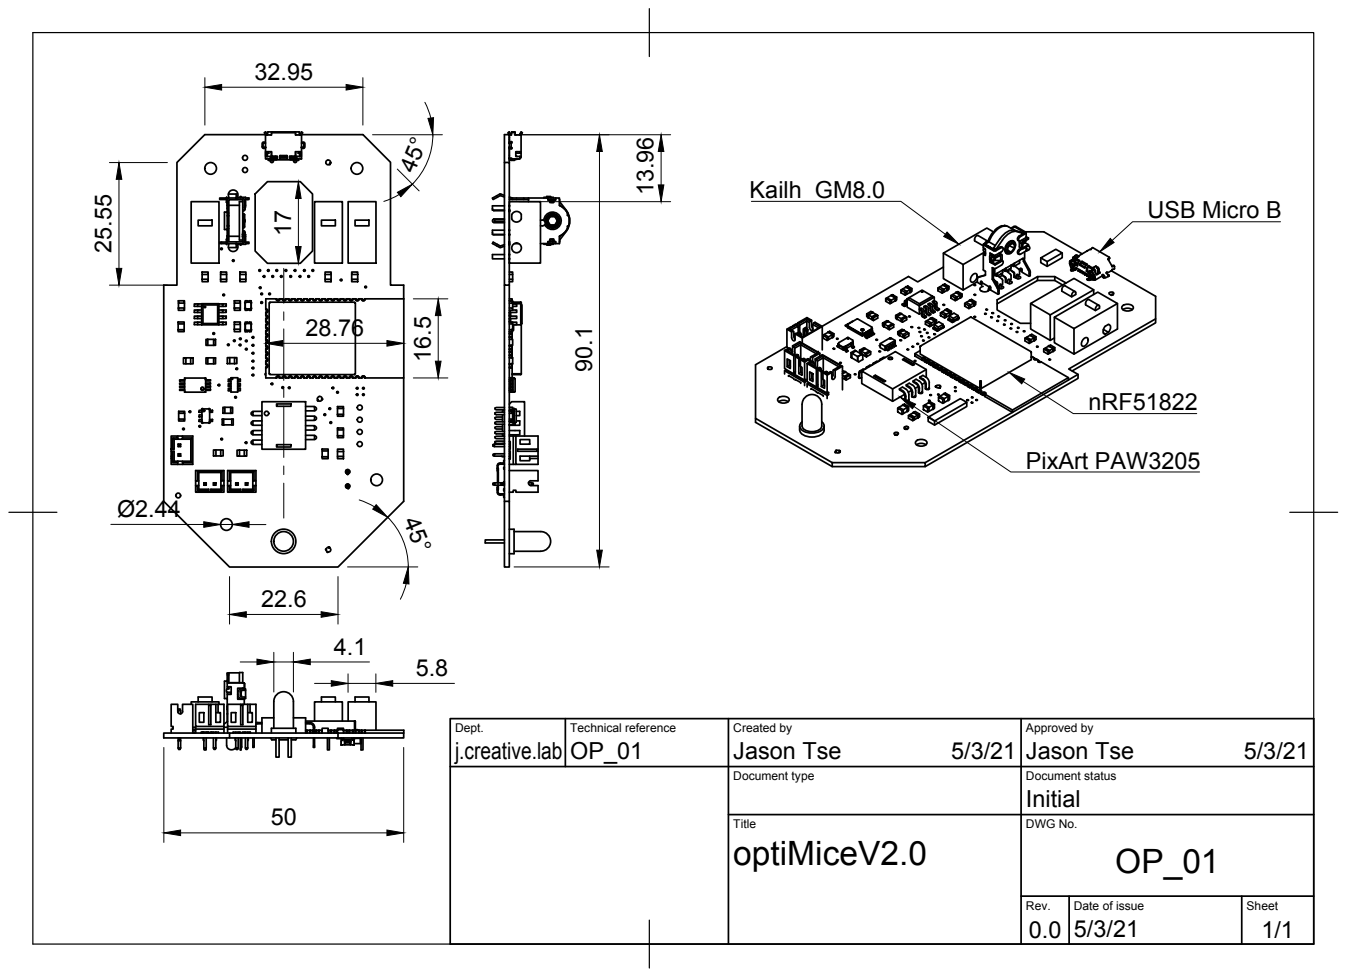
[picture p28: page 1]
Kailh GM8.0; PixArt PAW3205; USB Micro B

Dept. j.creative.lab | Technical reference OP_01 | Created by Jason Tse 5/3/21 | Approved by Jason Tse 5/3/21

Document type | Document status Initial

Title optiMiceV2.0 | DWG No. OP_01

Rev. 0.0 | Date of issue 5/3/21 | Sheet 1/1

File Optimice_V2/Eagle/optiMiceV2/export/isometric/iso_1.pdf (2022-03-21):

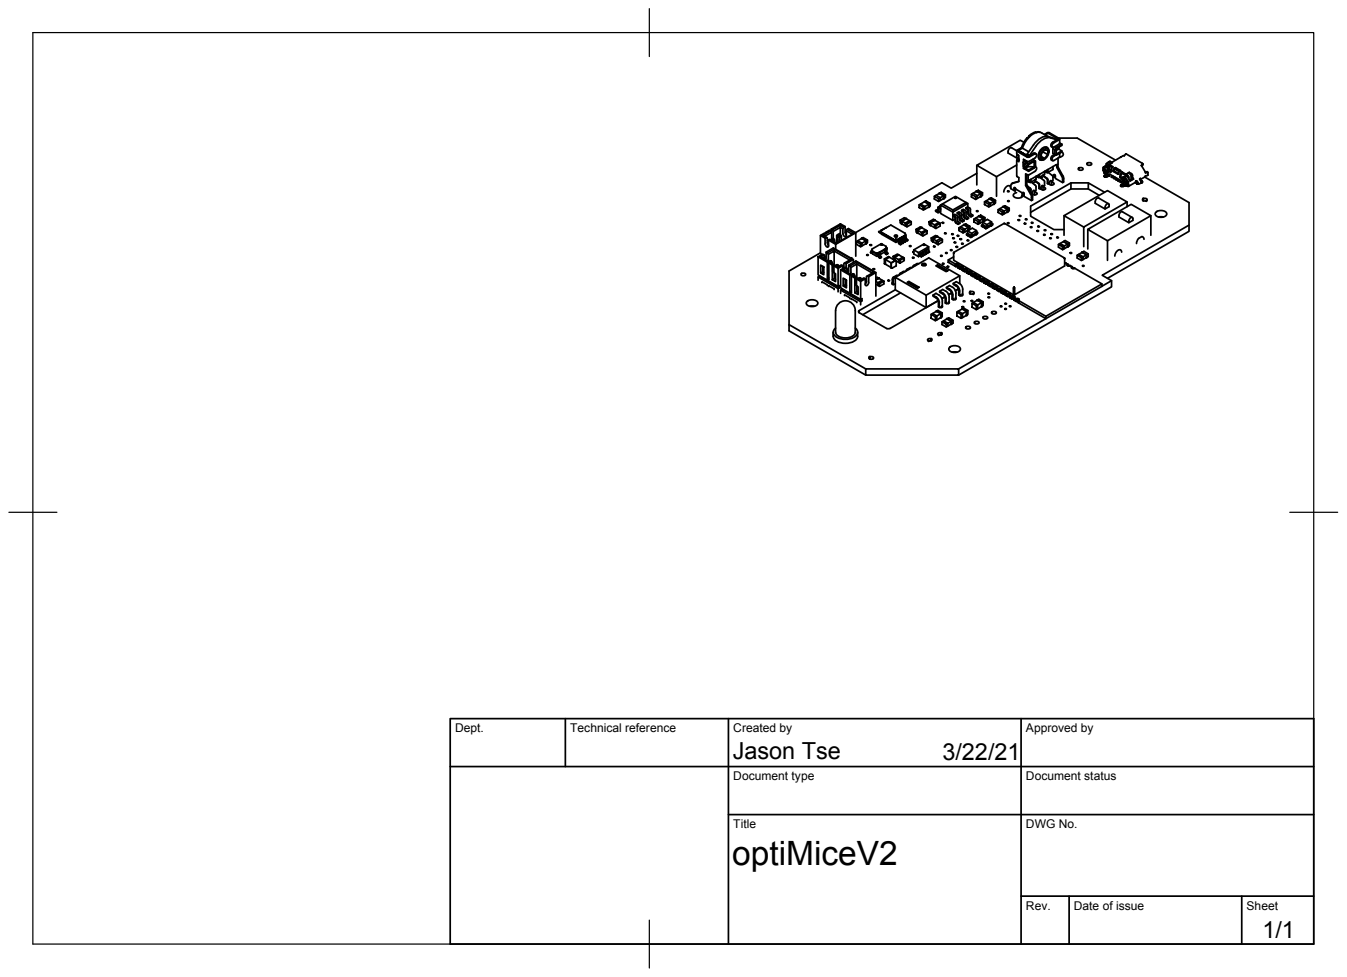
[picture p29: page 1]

Dept. | Technical reference | Created by Jason Tse 3/22/21 | Approved by

Document type | Document status

Title optiMiceV2 | DWG No.

Rev. | Date of issue | Sheet 1/1

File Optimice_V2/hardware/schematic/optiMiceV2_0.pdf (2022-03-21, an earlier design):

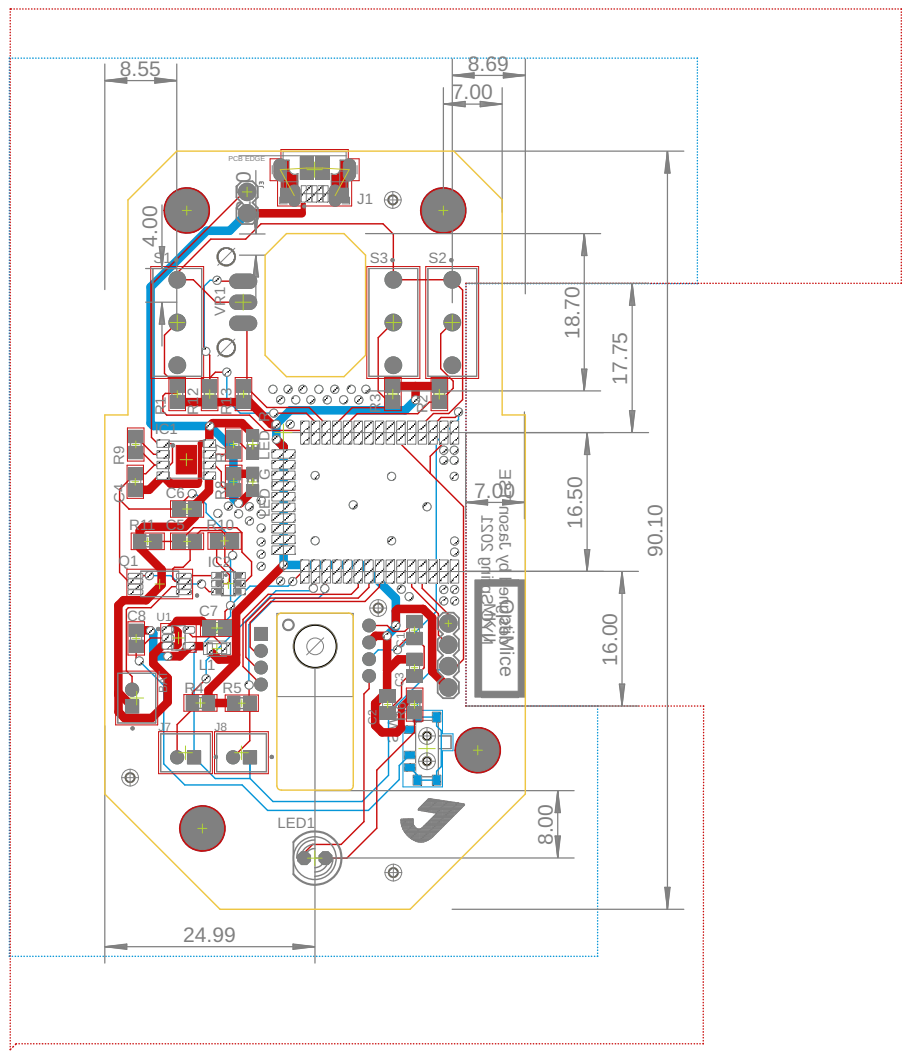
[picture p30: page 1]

designed by Jason TSE NYC Spring 2021 OptiMice MK II 18.70

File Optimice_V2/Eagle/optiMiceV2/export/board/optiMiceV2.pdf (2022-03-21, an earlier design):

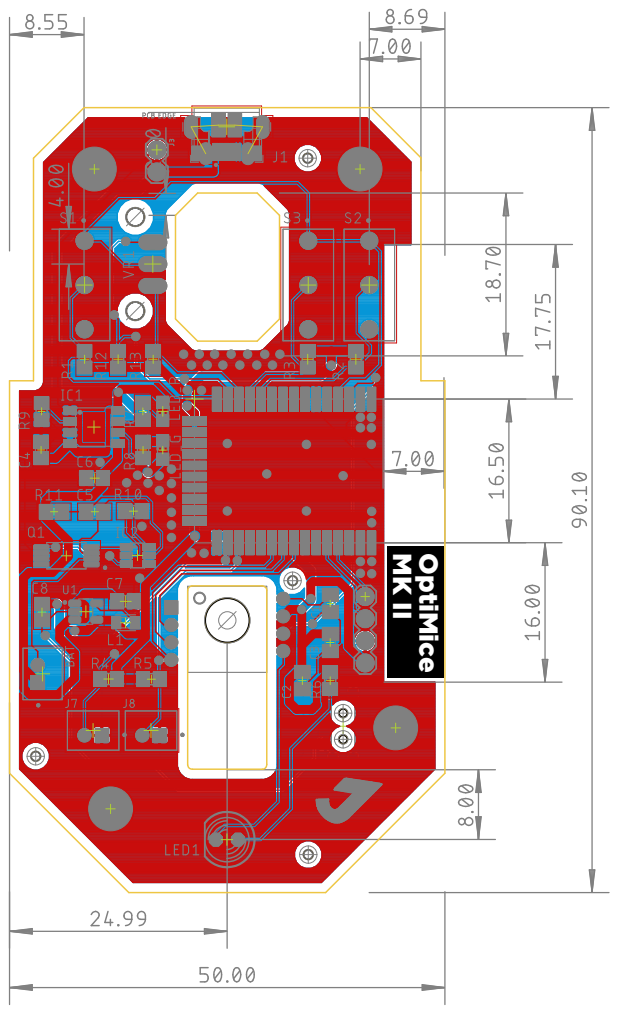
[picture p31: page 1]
OptiMice

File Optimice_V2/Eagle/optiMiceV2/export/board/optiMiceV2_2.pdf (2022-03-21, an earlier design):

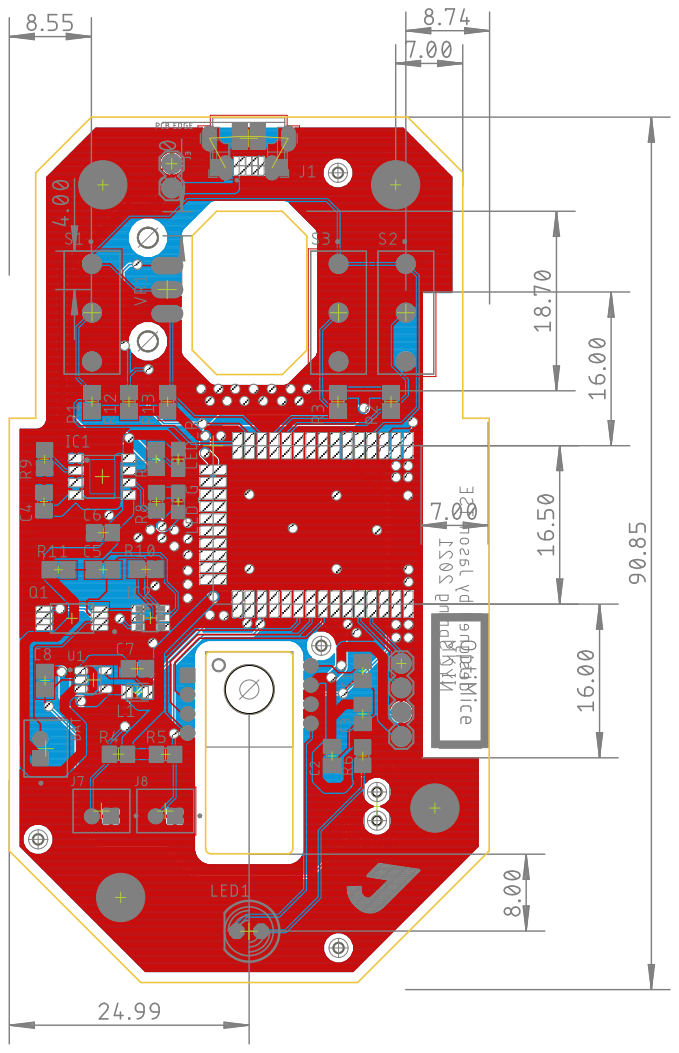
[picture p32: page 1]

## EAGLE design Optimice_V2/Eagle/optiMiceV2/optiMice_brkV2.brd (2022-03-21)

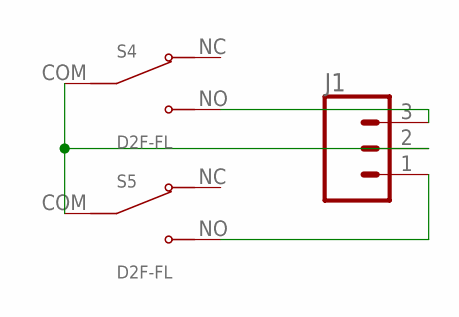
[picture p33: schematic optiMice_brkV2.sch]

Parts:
J1: CONN_03JST-PTH-VERT; JST-3-PTH-VERT
S4, S5: D2F-FL; SW_D2F-FL

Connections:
unnamed: J1.2, S4.COM, S5.COM
unnamed: J1.3, S4.NO
unnamed: J1.1, S5.NO

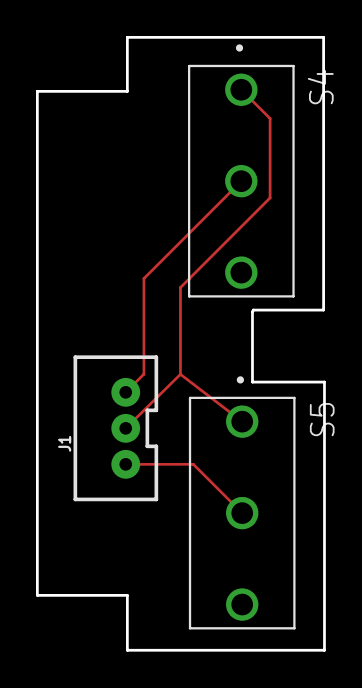
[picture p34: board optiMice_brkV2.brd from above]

Board: 2 copper layers, 15.9 x 34.0 mm, 3 parts (0 on the bottom side), 3 nets.

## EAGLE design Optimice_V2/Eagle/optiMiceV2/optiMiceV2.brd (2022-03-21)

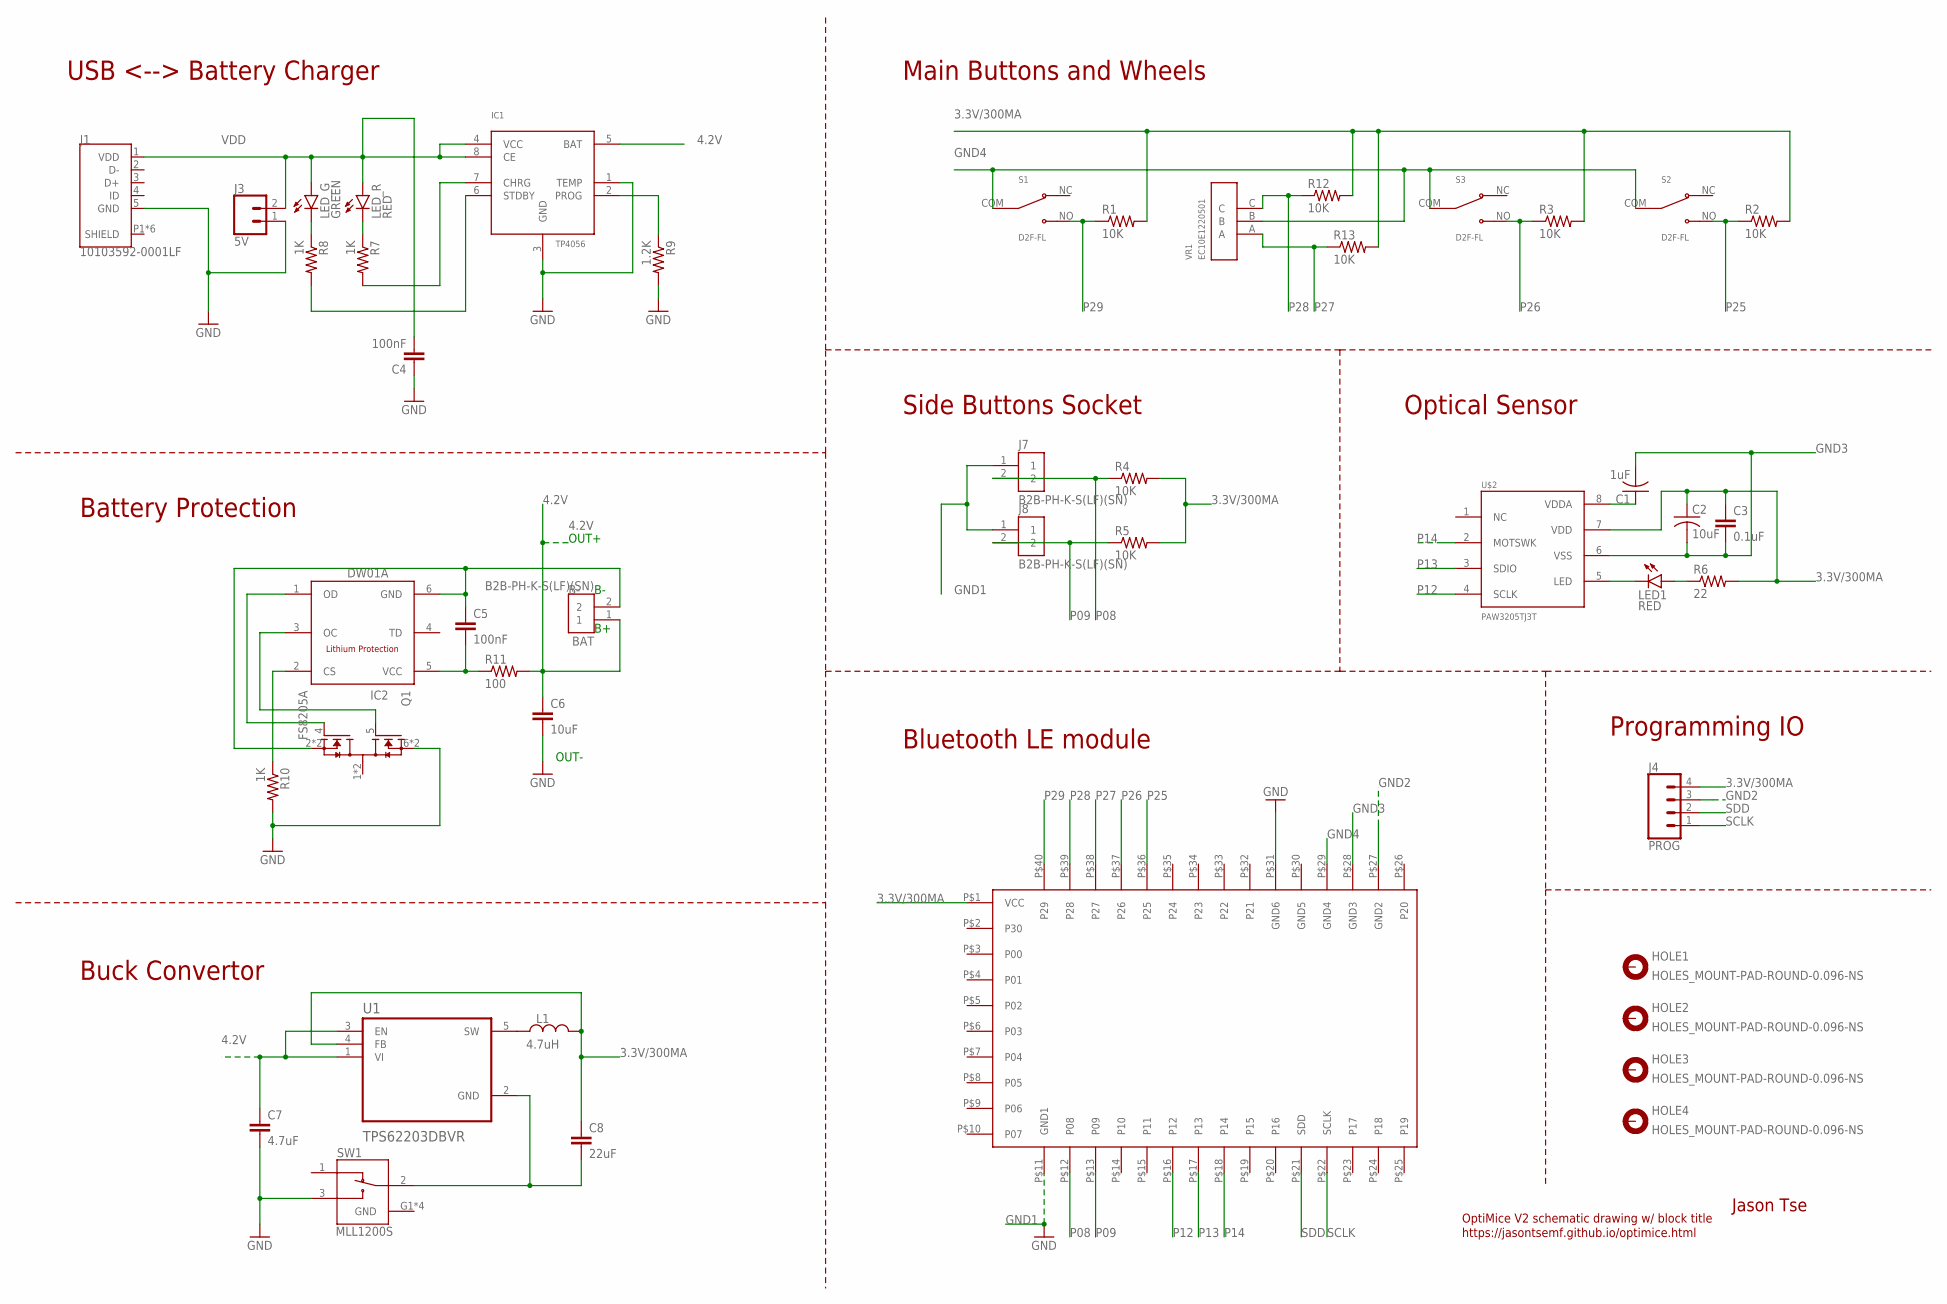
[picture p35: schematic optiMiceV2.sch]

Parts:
BAT: B2B-PH-K-S(LF)(SN); JST_B2B-PH-K-S(LF)(SN)
C1: 1uF; C0805K
C2: 10uF; C0805K
C3: 0.1uF; C0805K
C4, C5: 100nF; C0805
C6: 10uF; C0805
C7: 4.7uF; C0805
C8: 22uF; C0805
HOLE1, HOLE2, HOLE3, HOLE4: HOLES_MOUNT-PAD-ROUND-0.096-NS; HOLES_096-PAD-NS
IC1: TP4056; SOP-8
IC2: DW01A; SOT23-6
J1: 10103592-0001LF; AMPHENOL_10103592-0001LF
J3: 5V; 1X02
J4: PROG; 1X04
J7, J8: B2B-PH-K-S(LF)(SN); JST_B2B-PH-K-S(LF)(SN)
L1: 4.7uH; INDC2009X120
LED1: RED; LED5MM
LED_G: GREEN; CHIP-LED0805
LED_R: RED; CHIP-LED0805
Q1: FS8205A; SOP65P640X120-8N
R1, R2, R3, R4, R5, R12, R13: 10K; R0805
R6: 22; R0805
R7, R8, R10: 1K; R0805
R9: 1.2K; R0805
R11: 100; R0805
S1, S2, S3: D2F-FL; SW_D2F-FL
SW1: MLL1200S; SW_MLL1200S
U1: TPS62203DBVR; SOT95P280X145-5N
U$1: NRF51822-02; WT51822-S2
U$2: PAW3205TJ3T; PAW3205
VR1: EC10E1220501; TRIM_EC10E1220501

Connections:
3.3V/300MA: C2.1, C3.1, C8.1, J4.4, L1.2, R1.2, R2.2, R3.2, R4.2, R5.2, R6.2, R12.2, R13.2, U1.4 (FB), U$1.P$1 (VCC), U$2.7 (VDD)
4.2V: BAT.1, C6.1, C7.1, IC1.5 (BAT), R11.2, U1.1 (VI), U1.3 (EN)
B-: BAT.2, C5.1, IC2.6 (GND), Q1.2 (S1), Q1.3 (S1)
GND: C4.1, C6.2, C7.2, IC1.1 (TEMP), IC1.3 (GND), J1.5 (GND), J3.1, Q1.6 (S2), Q1.7 (S2), R9.2, R10.2, SW1.3, SW1.G1 (GND), SW1.G2 (GND), SW1.G3 (GND), SW1.G4 (GND), U$1.P$31 (GND6)
GND1: J7.1, J8.1, U$1.P$11 (GND1)
GND2: J4.3, U$1.P$27 (GND2)
GND3: C1.2, C2.2, C3.2, U$1.P$28 (GND3), U$2.6 (VSS)
GND4: S1.COM, S2.COM, S3.COM, U$1.P$29 (GND4), VR1.B
unnamed: C1.1, U$2.8 (VDDA)
unnamed: LED1.A, R6.1
unnamed: IC1.7 (CHRG), R7.2
unnamed: LED1.K (C), U$2.5 (LED)
unnamed: IC1.6 (STDBY), R8.2
unnamed: LED_R.C, R7.1
unnamed: LED_G.C, R8.1
unnamed: C8.2, SW1.2, U1.2 (GND)
unnamed: IC1.2 (PROG), R9.1
unnamed: L1.1, U1.5 (SW)
unnamed: IC2.3 (OC), Q1.5 (G2)
unnamed: IC2.1 (OD), Q1.4 (G1)
unnamed: C5.2, IC2.5 (VCC), R11.1
unnamed: IC2.2 (CS), R10.1
P08: J7.2, R4.1, U$1.P$12 (P08)
P09: J8.2, R5.1, U$1.P$13 (P09)
P12: U$1.P$16 (P12), U$2.4 (SCLK)
P13: U$1.P$17 (P13), U$2.3 (SDIO)
P14: U$1.P$18 (P14), U$2.2 (MOTSWK)
P25: R2.1, S2.NO, U$1.P$36 (P25)
P26: R3.1, S3.NO, U$1.P$37 (P26)
P27: R13.1, U$1.P$38 (P27), VR1.A
P28: R12.1, U$1.P$39 (P28), VR1.C
P29: R1.1, S1.NO, U$1.P$40 (P29)
SCLK: J4.1, U$1.P$22 (SCLK)
SDD: J4.2, U$1.P$21 (SDD)
SHIELD: J1.P1 (SHIELD), J1.P2 (SHIELD), J1.P3 (SHIELD), J1.P4 (SHIELD), J1.P5 (SHIELD), J1.P6 (SHIELD)
VDD: C4.2, IC1.4 (VCC), IC1.8 (CE), J1.1 (VDD), J3.2, LED_G.A, LED_R.A

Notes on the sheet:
OUT-
OUT+
USB <--> Battery Charger
Battery Protection
Buck Convertor
Side Buttons Socket
Main Buttons and Wheels
Optical Sensor
Programming IO
Bluetooth LE module
Jason Tse
OptiMice V2 schematic drawing w/ block title https://jasontsemf.github.io/optimice.html

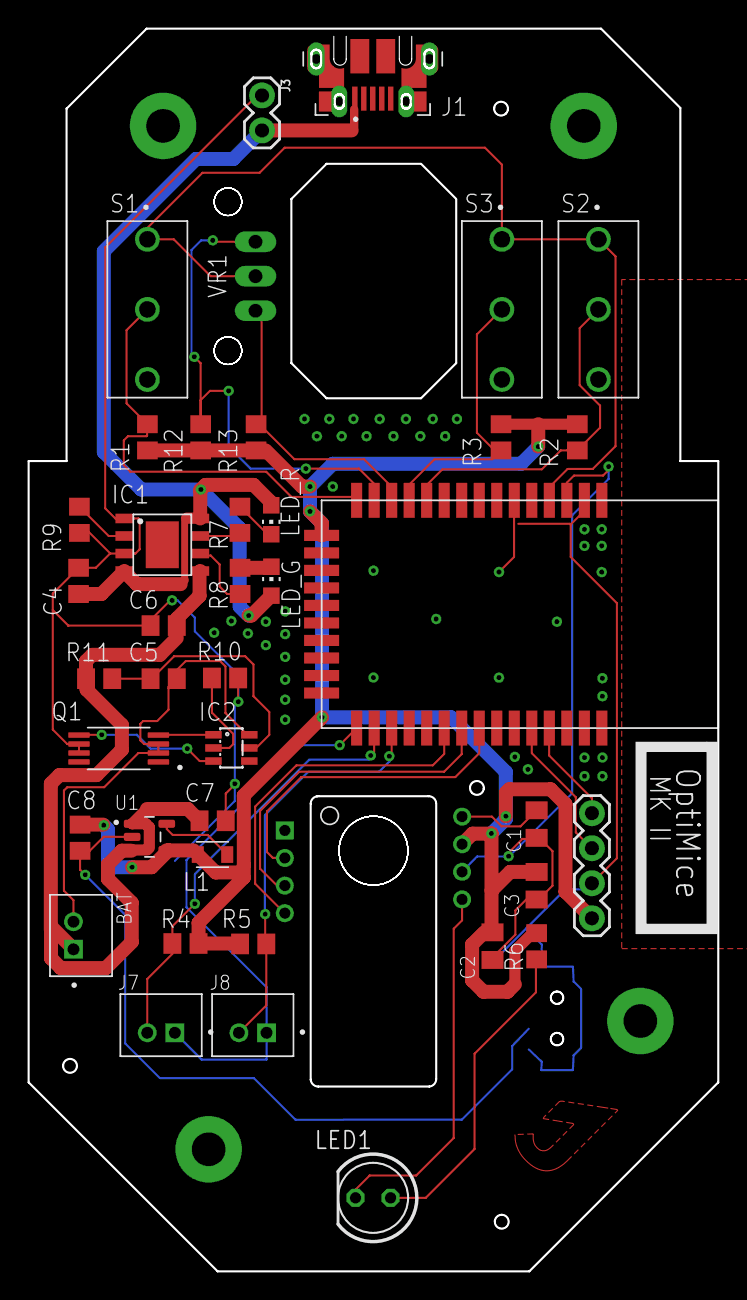
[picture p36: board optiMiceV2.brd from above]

Board: 2 copper layers, 50.0 x 90.1 mm, 46 parts (1 on the bottom side), 36 nets.

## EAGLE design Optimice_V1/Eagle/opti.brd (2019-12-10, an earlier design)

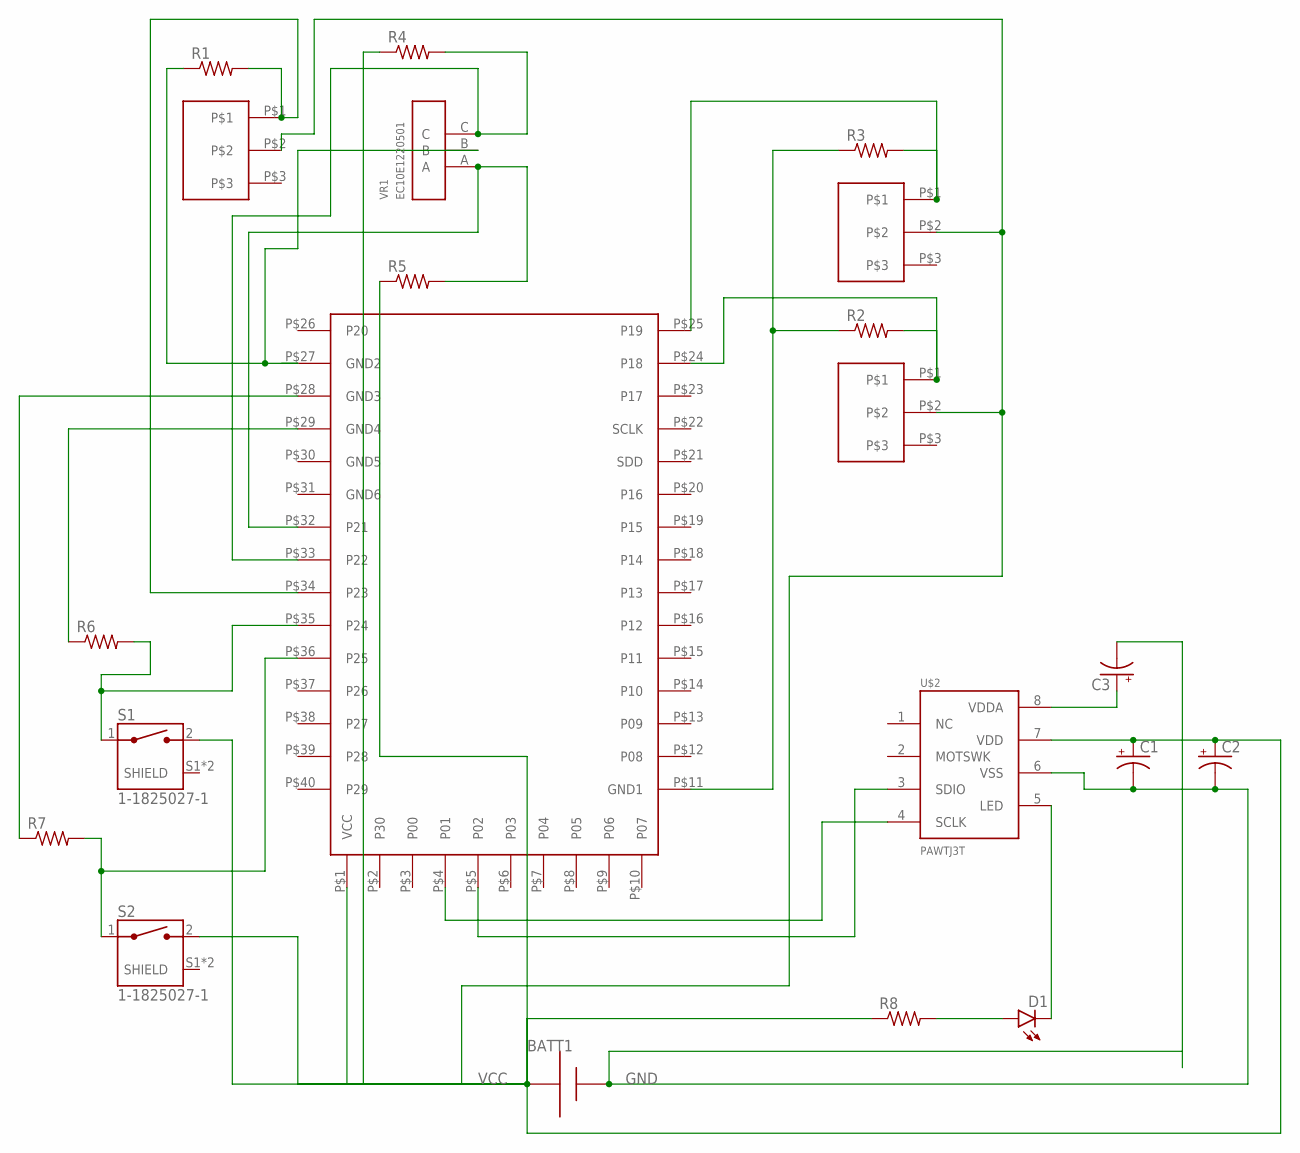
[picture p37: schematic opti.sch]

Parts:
BATT1: AAA; 12BH412
C1, C2, C3: CAPACITOR-PE2-5; E2-5
D1: BEAGLEBONE_BLUE_LED-3MM-NO_SILK; BEAGLEBONE_BLUE_BEAGLEBONE_BLUE_LED3MM-NS
R1, R2, R3, R4, R5, R6, R7, R8: R-US_0207/10; 0207/10
S1, S2: 1-1825027-1; SW_1-1825027-1
U$1: NRF51822-02; WT51822-S2
U$2: PAWTJ3T; ADNS-2080
U$3, U$4, U$5: D2FC
VR1: EC10E1220501; TRIM_EC10E1220501

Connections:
GND: BATT1.+, C1.-, C2.-, C3.-, U$2.6 (VSS)
unnamed: U$1.P$5 (P02), U$2.3 (SDIO)
unnamed: U$1.P$4 (P01), U$2.4 (SCLK)
unnamed: C3.+, U$2.8 (VDDA)
unnamed: R3.2, U$1.P$25 (P19), U$5.P$1
unnamed: R2.2, U$1.P$24 (P18), U$4.P$1
unnamed: R2.1, R3.1, U$1.P$11 (GND1)
unnamed: R4.2, U$1.P$33 (P22), VR1.C
unnamed: R5.2, U$1.P$32 (P21), VR1.A
unnamed: R6.2, S1.1, U$1.P$35 (P24)
unnamed: R7.2, S2.1, U$1.P$36 (P25)
unnamed: R1.1, U$1.P$27 (GND2), VR1.B
unnamed: R1.2, U$1.P$34 (P23), U$3.P$1
unnamed: R7.1, U$1.P$28 (GND3)
unnamed: R6.1, U$1.P$29 (GND4)
unnamed: D1.K (C), U$2.5 (LED)
unnamed: D1.A, R8.2
SHIELD: S1.S1 (SHIELD), S1.S2 (SHIELD), S2.S1 (SHIELD), S2.S2 (SHIELD)
VCC: BATT1.-, C1.+, C2.+, R4.1, R5.1, R8.1, S1.2, S2.2, U$1.P$1 (VCC), U$2.7 (VDD), U$3.P$2, U$4.P$2, U$5.P$2

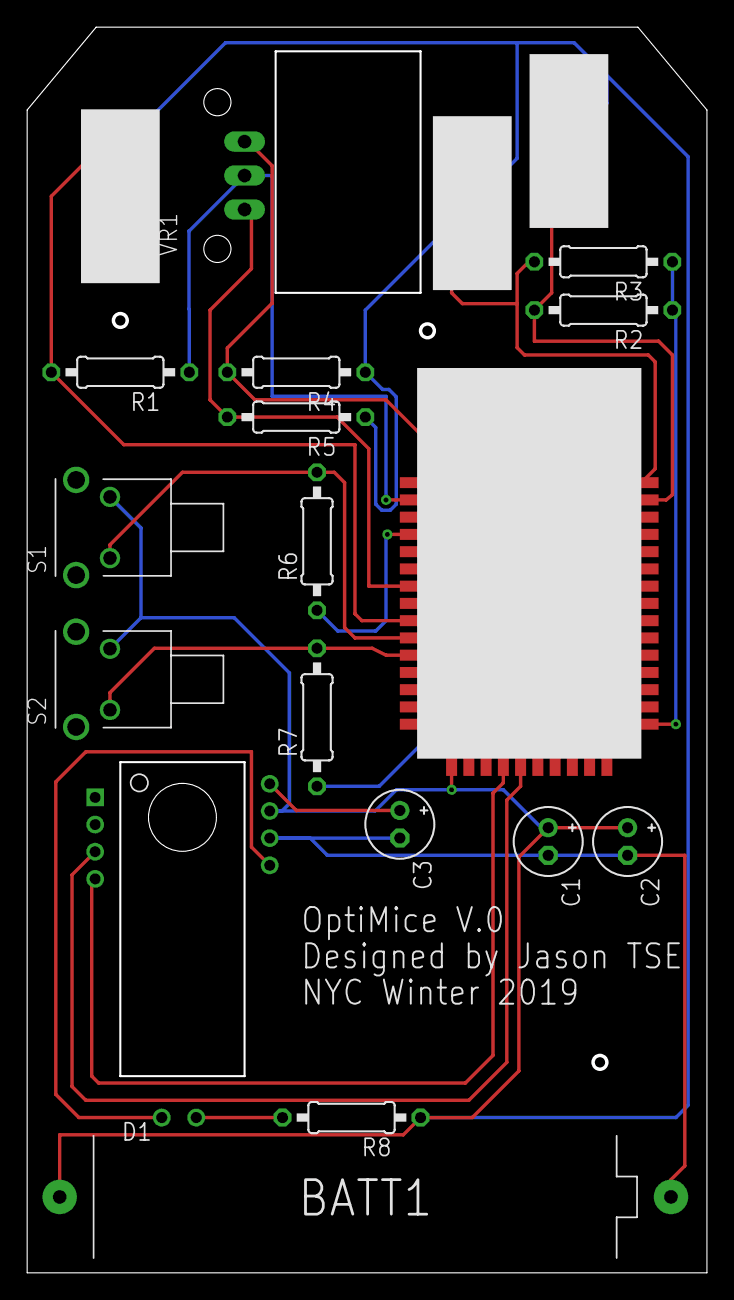
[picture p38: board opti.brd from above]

Board: 2 copper layers, 50.0 x 91.7 mm, 21 parts (0 on the bottom side), 19 nets.

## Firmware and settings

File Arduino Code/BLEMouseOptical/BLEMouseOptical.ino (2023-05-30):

#include <SPI.h>
#include <BLEPeripheral.h>
#include <BLEHIDPeripheral.h>
#include <BLEMouse.h>
#include <BLEKeyboard.h>
#include <BLEMultimedia.h>
#include <BLESystemControl.h>

//BLEHIDPeripheral bleHIDPeripheral = BLEHIDPeripheral(BLE_REQ, BLE_RDY, BLE_RST);
BLEHIDPeripheral bleHIDPeripheral = BLEHIDPeripheral();
BLEMouse bleMouse;
BLEKeyboard bleKeyboard;
BLEMultimedia bleMultimedia;
BLESystemControl bleSystemControl;

#define LMB 23
#define RMB 24
#define MMB 25
#define FB 35
#define BB 36
#define SCRLUP 22
#define SCRLDN 21
//#define SCRLUP 6
//#define SCRLDN 7

// optical mouse
const int OptiDataPin = 2;
const int OptiClkPin = 1;

int correctPId1 = 48;
int cnt1 = 0;

const uint8_t OptiRegDx = 0x03; // 0x03
const uint8_t OptiRegDy = 0x04; // 0x04
const uint8_t OptiRegMotion = 0x02;
const uint8_t OptiRegProd1 =0x00;

int32_t optiX;
int32_t optiY;
signed char optiProd1;
signed char optiMotion;

int16_t optiSpX;
int16_t optiSpY;

const unsigned int optiSpCof = 800; // 1000分率
const int optiSpDif = 1000;

char isOptiConnected = 0;

// mouse button state
int leftState;
int rightState;
int middleState;

// side buttons state
int forwardState;
int backwardState;

// wheel state
byte rollUp = 6;
byte rollDown = 7;

byte lastState = 0;
byte steps = 0;
int  cw = 0;
int mStep = 0;
byte rollUpState = 0;
byte rollDownState = 0;
byte State = 0;

void setup() {
  delay(100);
  Serial.begin(115200);
  
#if defined (__AVR_ATmega32U4__)
//  while(!Serial);
  delay(5000);
#endif

//setup optical
  pinMode (OptiClkPin, OUTPUT);
  pinMode (OptiDataPin, INPUT);
  
  noInterrupts();
  OptiSetup();
  interrupts();
  
//setup buttons
//  pinMode(PIN_BUTTON_A, INPUT);
//  pinMode(PIN_BUTTON_B, INPUT);
  pinMode(LMB, INPUT);
  pinMode(RMB, INPUT);
  pinMode(MMB, INPUT);
//  leftState = digitalRead(PIN_BUTTON_A);
//  rightState = digitalRead(PIN_BUTTON_B);
  leftState = digitalRead(LMB);
  rightState = digitalRead(RMB);
  middleState = digitalRead(MMB);

//setup side buttons
  pinMode(FB, INPUT);
  pinMode(BB, INPUT);
  forwardState = digitalRead(FB);
  backwardState = digitalRead(BB);
  
//setup wheel
  pinMode(SCRLUP, INPUT);
  pinMode(SCRLDN, INPUT);

  bleHIDPeripheral.clearBondStoreData();
  bleHIDPeripheral.setLocalName("OptiMice");
  bleHIDPeripheral.setDeviceName("OptiMice");
  
//   must be in this order bleKeyboard > bleMouse > bleMultimedia
  bleHIDPeripheral.addHID(bleSystemControl);
  bleHIDPeripheral.addHID(bleMultimedia);
  bleHIDPeripheral.addHID(bleMouse);
  bleHIDPeripheral.addHID(bleKeyboard);

  bleHIDPeripheral.begin();
  Serial.println(F("BLE HID Mouse"));
  
}

void loop() {
  BLECentral central = bleHIDPeripheral.central();

  if (central) {
    // central connected to peripheral
    Serial.print(F("Connected to central: "));
    Serial.println(central.address());

    while (central.connected()) {
      
//        Serial.print("id1=");
//        Serial.print(OptiProductId1(), DEC);
//        signed char x = OptiDx();
//        signed char y = OptiDy();
        Serial.print(" motion=");
        Serial.println(OptiIsMotion(), DEC);
//        Serial.print(" x=");
//        Serial.print(OptiDx(), DEC);
//        Serial.print(" y=");
//        Serial.println(OptiDy(), DEC);

      bleMouse.move(OptiDx(), OptiDy()*-1);
//      int tempLeftState = digitalRead(PIN_BUTTON_A);
      int tempLeftState = digitalRead(LMB);
      if (tempLeftState != leftState) {
        leftState = tempLeftState;
        if (leftState == LOW) {
          Serial.println(F("Left Mouse press"));
          bleMouse.press();
//          bleMultimedia.write(MMKEY_MUTE);
        } else {
          Serial.println(F("Left Mouse release"));
          bleMouse.release();
        }
      }
      
//      int tempRightState = digitalRead(PIN_BUTTON_B);
      int tempRightState = digitalRead(RMB);
      if (tempRightState != rightState) {
        rightState = tempRightState;
        if (rightState == LOW) {
          Serial.println(F("Right Mouse press"));
          bleMouse.press(MOUSEBTN_RIGHT_MASK);
        } else {
          Serial.println(F("Right Mouse release"));
          bleMouse.release(MOUSEBTN_RIGHT_MASK);
        }
      }
      
      int tempMiddleState = digitalRead(MMB);
      if (tempMiddleState != middleState) {
        middleState = tempMiddleState;
        if (middleState == LOW) {
          Serial.println(F("Middle Mouse press"));
          bleMouse.press(MOUSEBTN_MIDDLE_MASK);
        } else {
          Serial.println(F("Middle Mouse release"));
          bleMouse.release(MOUSEBTN_MIDDLE_MASK);
        }
      }   

      int tempForwardState = digitalRead(FB);
      if (tempForwardState != forwardState) {
        forwardState = tempForwardState;
        if (forwardState == LOW) {
          Serial.println(F("Forward Mouse press"));
          bleKeyboard.press(KEYCODE_ARROW_LEFT,KEYCODE_MOD_LEFT_GUI);
        } else {
          Serial.println(F("Forward Mouse release"));
          bleKeyboard.release(KEYCODE_ARROW_LEFT,KEYCODE_MOD_LEFT_GUI);
        }
      } 

      int tempBackwardState = digitalRead(BB);
      if (tempBackwardState != backwardState) {
        backwardState = tempBackwardState;
        if (backwardState == LOW) {
          Serial.println(F("Backward Mouse press"));
          bleKeyboard.press(KEYCODE_ARROW_RIGHT,KEYCODE_MOD_LEFT_GUI);
        } else {
          Serial.println(F("Backward Mouse release"));
          bleKeyboard.release(KEYCODE_ARROW_RIGHT,KEYCODE_MOD_LEFT_GUI);
        }
      } 

      //mouse move and scroll
      updateWheel();
    }

    // central disconnected
    Serial.print(F("Disconnected from central: "));
    Serial.println(central.address());
  }
  delay(4);
}

void updateWheel(){
  rollUpState = digitalRead(rollUp);
  rollDownState = digitalRead(rollDown) << 1;
  State = rollUpState | rollDownState;

  if (lastState != State){
    switch (State) {
      case 0:
        if (lastState == 2){
          steps++;
          cw = 1;
        }
        else if(lastState == 1){
          steps--;
          cw = -1;
        }
        break;
      case 1:
        if (lastState == 0){
          steps++;
          cw = 1;
        }
        else if(lastState == 3){
          steps--;
          cw = -1;
        }
        break;
      case 2:
        if (lastState == 3){
          steps++;
          cw = 1;
        }
        else if(lastState == 0){
          steps--;
          cw = -1;
        }
        break;
      case 3:
        if (lastState == 1){
          steps++;
          cw = 1;
        }
        else if(lastState == 2){
          steps--;
          cw = -1;
        }
        break;
    }
  }

  if(lastState != State && State != 2){
    bleMouse.move(0, 0, cw);
    Serial.print("scroll");
    Serial.print("\t");
    Serial.println("cw");
  }
  lastState = State;
  delay(1);
}

uint8_t OptiReadRegister(uint8_t address)
{
  int i = 7;
  uint8_t r = 0;
  // Write the address of the register we want to read:
  pinMode (OptiDataPin, OUTPUT);
  for (i=7; i>=0; i--)
  {
    digitalWrite (OptiClkPin, LOW);
    //delayMicroseconds(50);
    digitalWrite (OptiDataPin, address & (1 << i));
    delayMicroseconds(1);
    digitalWrite (OptiClkPin, HIGH);
    delayMicroseconds(5);
  }
  // Switch data line from OUTPUT to INPUT
  pinMode (OptiDataPin, INPUT);
  // Wait a bit...
  delayMicroseconds(30);
  // Fetch the data!
  for (i=7; i>=0; i--)
  {                             
    digitalWrite (OptiClkPin, LOW);
    delayMicroseconds(1);
    digitalWrite (OptiClkPin, HIGH);
    delayMicroseconds(4);
    r |= (digitalRead (OptiDataPin) << i);
    delayMicroseconds(1);
  }
  delayMicroseconds(25);
  return r;
}

void OptiWriteRegister(uint8_t address, uint8_t data)
{
  int i = 7;
  
  // Set MSB high, to indicate write operation:
  address |= 0x80;
  // Write the address:
  pinMode (OptiDataPin, OUTPUT);
  for (i=7; i>=0; i--)
  {
    digitalWrite (OptiClkPin, LOW);
    //delayMicroseconds(5);
    digitalWrite (OptiDataPin, address & (1 << i));
    delayMicroseconds(1);
    digitalWrite (OptiClkPin, HIGH);
    delayMicroseconds(5);
  }
  delayMicroseconds(30);
  // Write the data:
  for (i=7; i>=0; i--)
  {
    digitalWrite (OptiClkPin, LOW);
    //delayMicroseconds(5);
    digitalWrite (OptiDataPin, data & (1 << i));
    delayMicroseconds(1);
    digitalWrite (OptiClkPin, HIGH);
    delayMicroseconds(5);
  }
}

signed char OptiDx(){
  return  (signed char) OptiReadRegister(OptiRegDx);
}

signed char OptiDy(){
  return  (signed char) OptiReadRegister(OptiRegDy);
}

signed char OptiProductId1(){
  return  (signed char) OptiReadRegister(OptiRegProd1);
}

signed char OptiIsMotion(){
  signed char d = OptiReadRegister(OptiRegMotion);
  optiMotion = d;
  return optiMotion == -122 ? 1 : 0;
}

void OptiBegin(void)
{
  optiX = 0;
  optiY = 0;
  
  digitalWrite(OptiClkPin, HIGH);                     
  delayMicroseconds(5);
  digitalWrite(OptiClkPin, LOW);
  delayMicroseconds(1);
  digitalWrite(OptiClkPin, HIGH); 
  delay(100);
}

void OptiSetup(){
  int cnt = 0, PId1;
  pinMode (OptiClkPin, OUTPUT);
  pinMode (OptiDataPin, INPUT);
  Serial.println("OptiSetup");
  while(1){
  OptiBegin();
  PId1 = OptiProductId1();
  if( PId1 == correctPId1){
    isOptiConnected = 1;
    break;
  }
  cnt++;
  if(cnt % 10 == 0){
    //cnt = 0;
    Serial.print("Id = : ");
    Serial.println(PId1 ,DEC);
  }
  if(cnt == 100)
    break;
  delay(1);
 }

 
 Serial.println("\n break while!! \n");
 Serial.println(cnt, DEC);
  
  OptiWriteRegister(0x89, 0xA5);
  OptiWriteRegister(0x89, 0x00);
  OptiWriteRegister(0x86, 0x00);
  OptiWriteRegister(0x86, 0x04);
  OptiWriteRegister(0x85, 0xBC);
  delay(5);
  OptiWriteRegister(0x86, 0x08);
  delay(550);
  OptiWriteRegister(0x86, 0x80);
  delay(8);
  OptiWriteRegister(0x85, 0xB9);
  OptiWriteRegister(0x86, 0x80);
  OptiWriteRegister(0x86, 0x06);
  delay(32);
}

void OptiReconnect(){
  int PId1, cnt = 0;
  while(1){
    OptiBegin();
    PId1 = OptiProductId1();
    if( PId1 == correctPId1){
      break;
    }
    cnt++;
    if(cnt % 10 == 0){
     //cnt = 0;
      Serial.print("Id = : ");
      Serial.println(PId1 ,DEC);
    }
    if(cnt == 10)
    {
      isOptiConnected = 0;
      break;
    }
    delay(1);
  }  
}

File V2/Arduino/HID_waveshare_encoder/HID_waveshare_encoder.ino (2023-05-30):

// Copyright (c) Sandeep Mistry. All rights reserved.
// Licensed under the MIT license. See LICENSE file in the project root for full license information.

// Import libraries (BLEPeripheral depends on SPI)
#include <SPI.h>
#include <BLEHIDPeripheral.h>
#include <BLEMouse.h>

//#define BUTTON_LEFT_PIN 22
//#define BUTTON_RIGHT_PIN 25
//#define BUTTON_MID_PIN 24
//#define BUTTON_FOR_PIN 14
//#define BUTTON_BACK_PIN 13
#define BUTTON_LEFT_PIN 1
#define BUTTON_RIGHT_PIN 2
#define BUTTON_MID_PIN 3
#define BUTTON_FOR_PIN 4
#define BUTTON_BACK_PIN 5

#define JOYSTICK_X_AXIS_PIN A0
#define JOYSTICK_Y_AXIS_PIN A1
#define JOYSTICK_RANGE 24

// define pins (varies per shield/board)
#define BLE_REQ   9
#define BLE_RDY   8
#define BLE_RST   4

// create peripheral instance, see pinouts above
BLEHIDPeripheral bleHIDPeripheral = BLEHIDPeripheral(BLE_REQ, BLE_RDY, BLE_RST);
BLEMouse bleMouse;

int buttonLeftState = 0;
int buttonRightState = 0;
int buttonMidState = 0;
int buttonForState = 0;
int buttonBackState = 0;

int joystickXCenter;
int joystickYCenter;

byte rollUp = 21;
byte rollDown = 22;

byte lastState = 0;
byte steps = 0;
int  cw = 0;
byte rollUpState = 0;
byte rollDownState = 0;
byte State = 0;

void setup() {
  Serial.begin(9600);
#if defined (__AVR_ATmega32U4__)
  while (!Serial);
#endif

  pinMode(BUTTON_LEFT_PIN, INPUT);
  pinMode(BUTTON_RIGHT_PIN, INPUT);
  pinMode(BUTTON_MID_PIN, INPUT);
  pinMode(BUTTON_FOR_PIN, INPUT);
  pinMode(BUTTON_BACK_PIN, INPUT);

  pinMode(rollUp, INPUT);
  pinMode(rollDown, INPUT);
  pinMode(A0, OUTPUT);

  buttonLeftState = digitalRead(BUTTON_LEFT_PIN);
  buttonRightState = digitalRead(BUTTON_RIGHT_PIN);
  buttonMidState = digitalRead(BUTTON_MID_PIN);
  buttonForState = digitalRead(BUTTON_FOR_PIN);
  buttonBackState = digitalRead(BUTTON_BACK_PIN);

  //  if (buttonLeftState == LOW) {
  //    Serial.println(F("BLE HID Peripheral - clearing bond data"));
  //
  //    // clear bond store data
  //    bleHIDPeripheral.clearBondStoreData();
  //  }

  bleHIDPeripheral.clearBondStoreData();
  bleHIDPeripheral.setDeviceName("Arduino BLE HID w");
  bleHIDPeripheral.setLocalName("HID Mouse");
  bleHIDPeripheral.addHID(bleMouse);

  bleHIDPeripheral.begin();

  Serial.println(F("BLE HID Mouse"));

  //  joystickXCenter = readJoystickAxis(JOYSTICK_X_AXIS_PIN);
  //  joystickYCenter = readJoystickAxis(JOYSTICK_Y_AXIS_PIN);
}

void loop() {
  BLECentral central = bleHIDPeripheral.central();

  if (central) {
    // central connected to peripheral
    Serial.print(F("Connected to central: "));
    Serial.println(central.address());

    while (central.connected()) {
      // 11 does not light up
      // 9 is always lit
      pinMode(9, OUTPUT);
      digitalWrite(9, HIGH);
      //      int tempButtonState = digitalRead(JOYSTICK_BUTTON_PIN);
      int tempButtonLeftState = digitalRead(BUTTON_LEFT_PIN);
      //      if (tempButtonState != buttonState) {
      if (tempButtonLeftState != buttonLeftState) {
        //        buttonState = tempButtonState;
        buttonLeftState = tempButtonLeftState;
        if (buttonLeftState == LOW) {
          Serial.println(F("Left Mouse press"));
          bleMouse.press();
        } else {
          Serial.println(F("Left Mouse release"));
          bleMouse.release();
        }
      }

      int tempRightLeftState = digitalRead(BUTTON_RIGHT_PIN);
      //      if (tempButtonState != buttonState) {
      if (tempRightLeftState != buttonRightState) {
        //        buttonState = tempButtonState;
        buttonRightState = tempRightLeftState;
        if (buttonRightState == LOW) {
          Serial.println(F("Mid Mouse press"));
          bleMouse.press(MOUSEBTN_RIGHT_MASK);
        } else {
          Serial.println(F("Left Mouse release"));
          bleMouse.release(MOUSEBTN_RIGHT_MASK);
        }
      }

      int tempMidLeftState = digitalRead(BUTTON_MID_PIN);
      //      if (tempButtonState != buttonState) {
      if (tempMidLeftState != buttonMidState) {
        //        buttonState = tempButtonState;
        buttonMidState = tempMidLeftState;
        if (buttonMidState == LOW) {
          Serial.println(F("Mid Mouse press"));
          bleMouse.press(MOUSEBTN_MIDDLE_MASK);
        } else {
          Serial.println(F("Left Mouse release"));
          bleMouse.release(MOUSEBTN_MIDDLE_MASK);
        }
      }

      rollUpState = digitalRead(rollUp);
      rollDownState = digitalRead(rollDown) << 1;
      State = rollUpState | rollDownState;

      if (lastState != State) {
        switch (State) {
          case 0:
            if (lastState == 2) {
              steps++;
              cw = 1;
            }
            else if (lastState == 1) {
              steps--;
              cw = -1;
            }
            break;
          case 1:
            if (lastState == 0) {
              steps++;
              cw = 1;
            }
            else if (lastState == 3) {
              steps--;
              cw = -1;
            }
            break;
          case 2:
            if (lastState == 3) {
              steps++;
              cw = 1;
            }
            else if (lastState == 0) {
              steps--;
              cw = -1;
            }
            break;
          case 3:
            if (lastState == 1) {
              steps++;
              cw = 1;
            }
            else if (lastState == 2) {
              steps--;
              cw = -1;
            }
            break;
        }
      }

      if (State != lastState) {
        int x = 0;
        int y = 0;
        //      int x = readJoystickAxis(JOYSTICK_X_AXIS_PIN) - joystickXCenter;
        //      int y = readJoystickAxis(JOYSTICK_Y_AXIS_PIN) - joystickYCenter;


        bleMouse.move(x, y, cw);

        lastState = State;
        Serial.print(State);
        Serial.print("\t");
        Serial.print(cw);
        Serial.print("\t");
        Serial.println(steps);
        delay(1);
      }

      //      int x = 0;
      //      int y = 0;
      //      //      int x = readJoystickAxis(JOYSTICK_X_AXIS_PIN) - joystickXCenter;
      //      //      int y = readJoystickAxis(JOYSTICK_Y_AXIS_PIN) - joystickYCenter;
      //
      //      if (x || y) {
      //        bleMouse.move(x, y);
      //      }
    }

    // central disconnected
    Serial.print(F("Disconnected from central: "));
    Serial.println(central.address());
  }
}

int readJoystickAxis(int pin) {
  int rawValue = analogRead(pin);
  int mappedValue = map(rawValue, 0, 1023, 0, JOYSTICK_RANGE);
  int centeredValue = mappedValue - (JOYSTICK_RANGE / 2);

  return (centeredValue * -1); // reverse direction
}

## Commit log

2022-03-21 Move all old contents into V1
    [opti.brd, opti.sch]
2022-03-21 Created V2
    [hand_reorient.obj, hand_reorient_cuthalf_flat_v2.obj, jason_hand_1.obj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]
2022-03-21 Moved minimal hand into v2 software
    [output_mesh_lixel.obj, output_mesh_lixelMar112021181230.obj, output_mesh_lixel_1.obj]
2022-03-21 meshnet with snapshot 8
    [output_mesh_lixel.obj, output_mesh_param.obj]

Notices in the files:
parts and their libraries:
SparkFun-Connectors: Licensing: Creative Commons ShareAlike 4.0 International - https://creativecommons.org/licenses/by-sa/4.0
